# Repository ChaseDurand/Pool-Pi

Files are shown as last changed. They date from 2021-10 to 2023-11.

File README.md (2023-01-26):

# Logo icon Pool-Pi

Pool-Pi is a hardware+software system for interfacing with Goldline/Hayward Aqualogic pool control boards over WiFi via a Raspberry Pi. It adds wireless capabilities to non-wireless control boards and a web interface for viewing updates and sending commands.

<p align='center'>
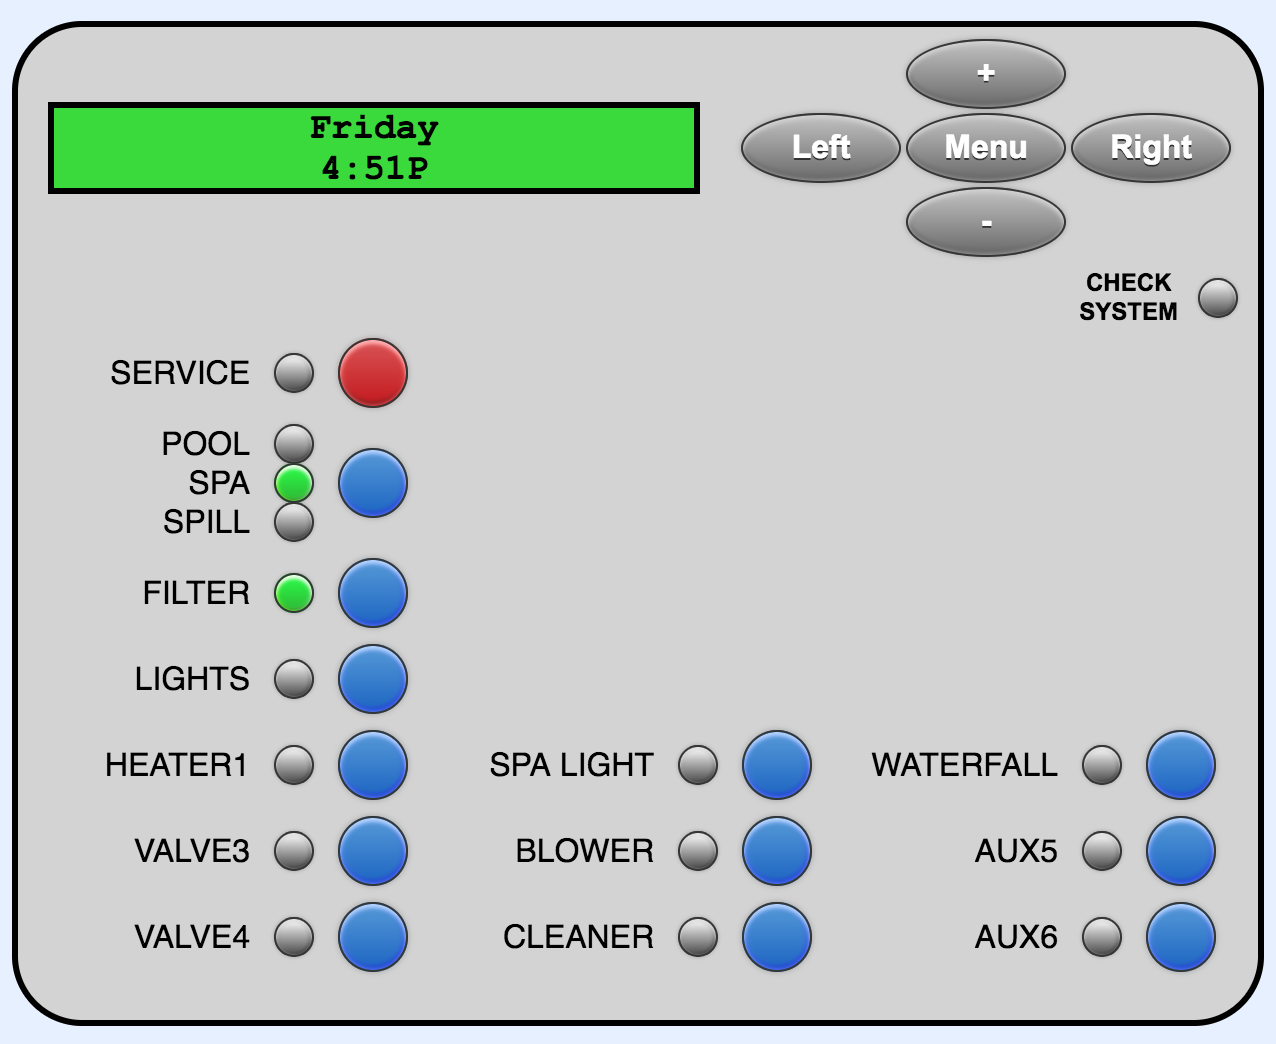
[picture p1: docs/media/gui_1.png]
    
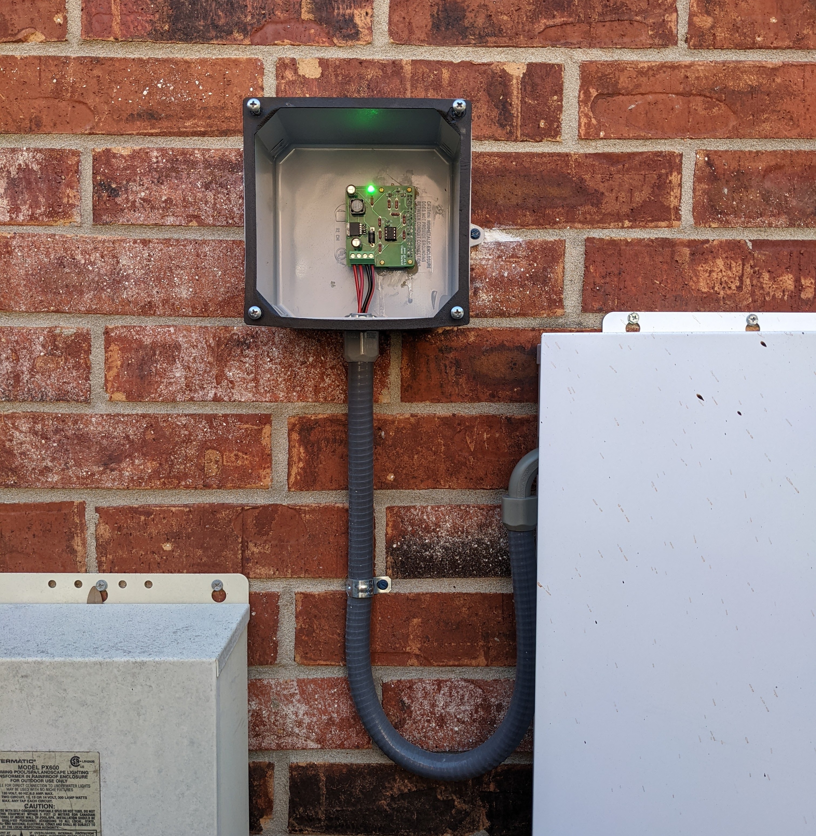
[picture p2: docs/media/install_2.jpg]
    
</p>

## Demo Video
This video shows multiple clients interfacing with the unit and demonstrates display updates, button presses, menu controls, blinking display characters, and LED updates.

https://user-images.githubusercontent.com/50851884/149863222-32523871-b4b8-4c59-9fa8-fe185a0315eb.mov

## Overview
<p align='center'>
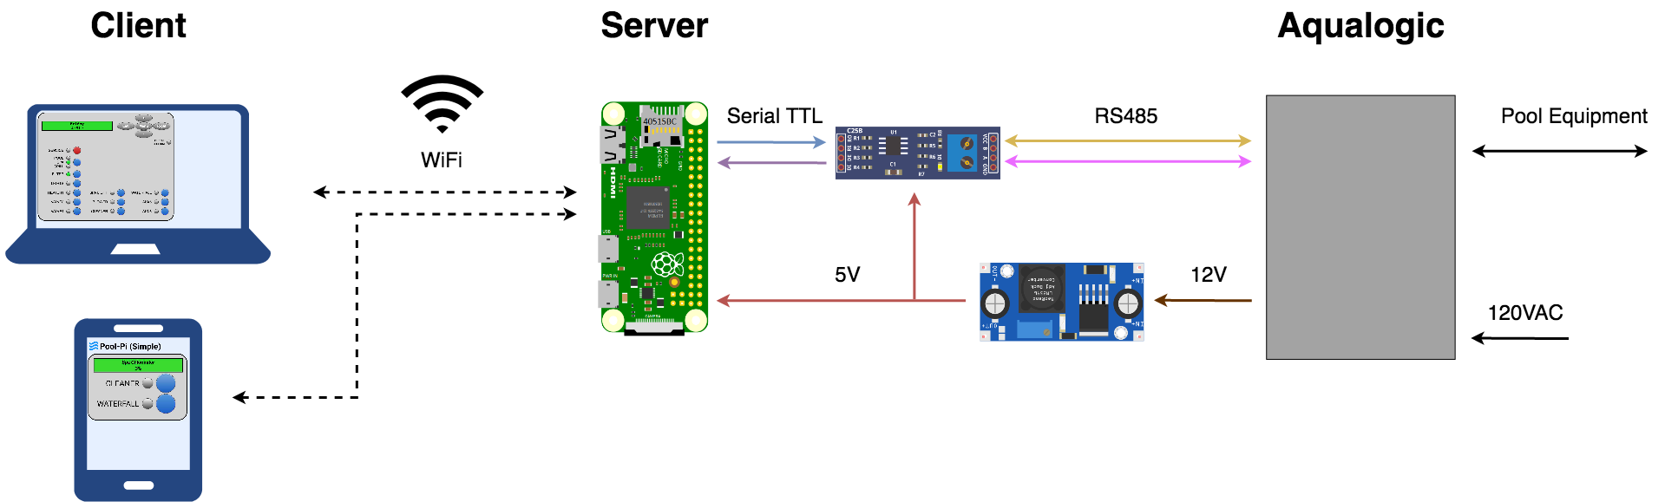
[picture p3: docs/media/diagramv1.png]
Diagram

</p>

Pool-Pi provides a web interface which emulates a local PS-8 display, allowing for the same controls accessible from the physical unit. The serial bus exposes all 14 aux relays regardless of local display, so emulation of a PS-16 display is possible, allowing additional relays to be added without purchasing a larger local interface. An RS485 adapter is used to read and send messages in accordance with the [Aqualogic serial communication protocol](/docs/PROTOCOL_NOTES.md), mimicking an OEM device. The system also adds logging, which is unavailable on the OEM unit. A simplified GUI is available to show the most frequently used commands.
<p align='center'>
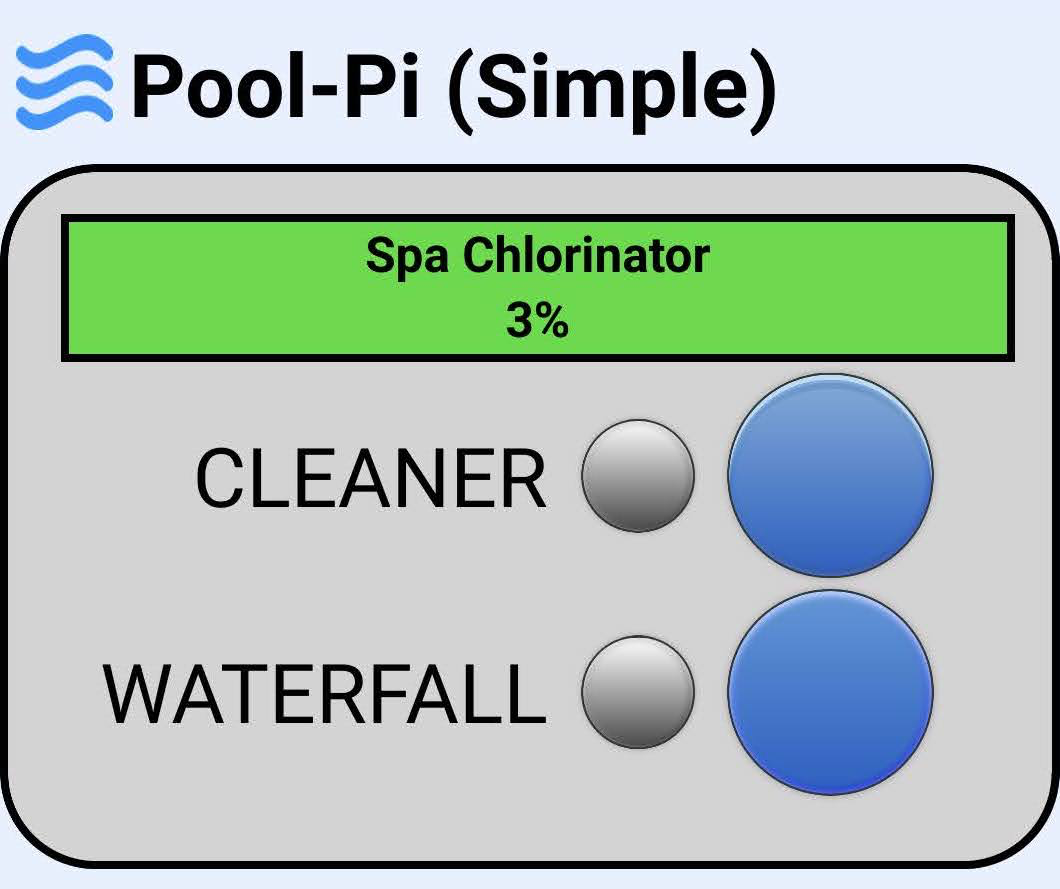
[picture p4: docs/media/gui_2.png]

</p>

## Setup
Project requirements and instructions can be found in [docs/SETUP.md](/docs/SETUP.md).

## Acknowledgements
Thank you to other people who have put their own resources/solutions for solving this problem online, including [draythomp](http://www.desert-home.com/), [swilson](https://github.com/swilson/aqualogic), and Pete Tompkins.

## Disclaimer
This project is not endorsed or affiliated with Goldline/Hayward in any way.

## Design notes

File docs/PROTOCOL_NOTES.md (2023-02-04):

# Aqualogic RS485 Protocol Notes

The RS485 protocol that the Aqualogic board uses is not fully documented. The most official information can be found in the manual for the AQ-CO-SERIAL, a device designed to interface between a Prologic/Aqualogic unit and a home automation system by converting RS485 messages to RS232. However, the AQ-CO-SERIAL strips some messages from the serial bus, slightly modifies some commands, and handles response timing to the master unit, so a substitute must handle all messages and timing.

The serial bus is used to communicate between the Aqualogic board, the local display, and any additional devices (wired controllers, spa controllers, wireless adapters such as the GLX-BASE-RF). All devices on the bus are connected in parallel.

The protocol use 1 start bit, 8 data bits, no parity, and 2 stop bits with a baud rate of 19.2k.

Frames are structured with DLE STX (x10x02), two bytes indicating the origin device and command, multiple data bytes, a two byte checksum, and DLE ETX (x10x03). The two byte checksum includes all bytes before the checksum (excluding DLE STX). If any byte besides the start and end DLE (x10) are equal to x10, a NULL (x00) is inserted immediately after that byte. This NULL must be removed when parsing frames.

| Start | Frame Type | Command/Data | Checksum | End |
| :---: | :---:| :---: | :---: | :---: |
| x10x02 | <2 bytes> | <0-? bytes> | <2 bytes> | x10x03 |

## Aqualogic to Controller
The Aqualogic board acts as a master unit providing a heartbeat/keep alive packet, screen updates, and LED updates.

A keep alive frame is sent every 100ms with a frame type of x01x01 and zero data bytes. If any serial device has a message to send, it must respond immediately after the keep alive frame. OEM controllers and display devices begin responding 0.5ms after the end of the keep alive frame. The Aqualogic sends any other commands 40ms after the end of the keep alive packet.

Keep alive frame: x10x02x01x01x00x14x10x03

Screen updates have the frame type x01x03. Different devices have different screen sizes (2 by 16 instead of 2 by 20). I do not know if different display packets are sent, or if the local displays parse frames differently to accomodate different screen sizes. There might be a handshake between the Aqualogic and any connected devices on startup to communicate screen size and software versions (which could also explain Communication Err 1). A NULL x00 is inserted after the display bytes.

Blinking characters are used to indicate selections on menus and time. To indicated blinking, the highest bit (1<<7) is set as 1 on a per character basis. For example, the colon symbol : almost always appears as blinking (xBA instead of x3A).

The degree symbol ° is encoded as an underscore (x5F) and must be replaced with xC2xB0.

In service mode, regular screen updates have the frame type of x02x03 and are immediately followed with display updates containing info about service mode with frame type of x03x03. The local display only displays the initial x02x03 update. The x03x03 service mode update is logged.

LED updates have the frame type x01x02. The first 4 bytes indicate on/off, and the second 4 bytes indicate blinking (if the corresponding on/off bit is also on). Within the bytes, a single bit corresponds to a specific LED.

| Start | Frame Type | LEDs1 | LEDs2 | LEDs3 | LEDs4 | Blink LEDs1 | Blink LEDs2 | Blink LEDs3 | Blink LEDs4 | Checksum | End |
| :---: | :---:| :---: | :---: | :---: | :---: | :---: | :---:| :---: | :---: | :---: | :---: |
| x10x02 | x01x02 | <1 byte> | <1 byte> | <1 byte> | <1 byte> | <1 byte> | <1 byte> | <1 byte> | <1 byte> | <2 bytes> | x10x03 |

The bit mask for each LED is shown below. The order of the LEDs is unintuitive because it reflects the evolution of the platform and its capabilities (AQL-P-4 to PS-8 to PS-16, each adding more parameters):

Example LED frame with Pool, Filter, and Aux4 On: x10x02x01x02x28x08x00x00x00x00x00x00x00x45x10x03

| Byte | Bit | Mask | LED |
| :---: | :---:| :---: | :--- |
| LEDs1 | 0 | 1<<0 | Heater1 |
| LEDs1 | 1 | 1<<1 | Valve3 |
| LEDs1 | 2 | 1<<2 | Check System |
| LEDs1 | 3 | 1<<3 | Pool |
| LEDs1 | 4 | 1<<4 | Spa |
| LEDs1 | 5 | 1<<5 | Filter |
| LEDs1 | 6 | 1<<6 | Lights |
| LEDs1 | 7 | 1<<7 | Aux1 |
| LEDs2 | 0 | 1<<0 | Aux2 |
| LEDs2 | 1 | 1<<1 | Service |
| LEDs2 | 2 | 1<<2 | Aux3 |
| LEDs2 | 3 | 1<<3 | Aux4 |
| LEDs2 | 4 | 1<<4 | Aux5 |
| LEDs2 | 5 | 1<<5 | Aux6 |
| LEDs2 | 6 | 1<<6 | Valve4/Heater2 |
| LEDs2 | 7 | 1<<7 | Spillover |
| LEDs3 | 0 | 1<<0 | System Off |
| LEDs3 | 1 | 1<<1 | Aux7 |
| LEDs3 | 2 | 1<<2 | Aux8 |
| LEDs3 | 3 | 1<<3 | Aux9 |
| LEDs3 | 4 | 1<<4 | Aux10 |
| LEDs3 | 5 | 1<<5 | Aux11 |
| LEDs3 | 6 | 1<<6 | Aux12 |
| LEDs3 | 7 | 1<<7 | Aux13 |
| LEDs4 | 0 | 1<<0 | Aux14 |
| LEDs4 | 1 | 1<<1 | Super Chlorinate |
| LEDs4 | 2 | 1<<2 | (unused) |
| LEDs4 | 3 | 1<<3 | (unused) |
| LEDs4 | 4 | 1<<4 | (unused) |
| LEDs4 | 5 | 1<<5 | (unused) |
| LEDs4 | 6 | 1<<6 | (unused) |
| LEDs4 | 7 | 1<<7 | (unused) |

## Controller to Aqualogic
Even though the PS-4/8/16 remotes know the state of the pool system through LED messages, all commands from this series act as toggle switches and are independent of the current state; There are no separate on/off commands for this series of remotes. The frame type from a local PS-8 is x00x02.

Example Aux 1 button toggle frame: x10x02x00x02x00x02x00x00x00x02x00x00x00x1Cx10x03. If Aux 1 is off, this will turn it on. If Aux 1 is on, this will turn it off.

| Function | Command |
| :--- | :--- |
| Service | x08x00x00x00 |
| Pool/Spa/Spillover | x40x00x00x00 |
| Filter | x00x80x00x00 |
| Lights | x00x01x00x00 |
| Heater1 | x00x00x04x00 |
| Valve3 | x00x00x01x00 |
| Aux1 | x00x02x00x00 |
| Aux2 | x00x04x00x00 |
| Aux3 | x00x08x00x00 |
| Aux4 | x00x10x00x00<sup>[1](#footnote1)</sup> |
| Aux5 | x00x20x00x00 |
| Aux6 | x00x40x00x00 |
| Aux7 | x00x80x00x00 |
| Aux8 | x00x00x08x00 |
| Aux9 | x00x00x10x00<sup>[1](#footnote1)</sup> |
| Aux10 | x00x00x20x00 |
| Aux11 | x00x00x40x00 |
| Aux12 | x00x00x80x00 |
| Aux13 | x00x00x00x01 |
| Aux14 | x00x00x00x02 |

## Variable Speed Pump Control
Aqualogic supports Hayward variable speed pumps that send their own frame type with speed and power information. I don't have a Hawyard VSP, so I am not able to implement support.

## Configuration Menu
The configuration menu is used for the Aqualogic's initial setup and when connecting new pool equipment. The configuration menu is unlocked by holding the left and right menu buttons for a few seconds. Because this sub-menu is seldom used and would only be used when the user is physically present with the Aqualogic, I did not implemenet it.

## Exposing Additional Aux Relays
The PS-4/8/16 boards use the same PCB, so each board can support up to 14 aux relays regardless of local interface. Because Pool-Pi can expose all of the available aux controls, additional relays could be added and controlled without purchasing a larger PS-8/16 local display.

## Legacy On/Off Commands
While commands from the PS-4/8/16 series are the same for on/off, older controllers such as the AQL-SS-RF and AQL-P-4 use slightly modified commands with separate on/off capabilities. The frame type is x00x05. The commands are repeated twice and end with x7F before the checksum. While using these commands would make programming far easier, these on/off commands only cover a subset of the PS-4/8/16 controls. Because my setup involves commands outside of this subset and I achieved high reliability with only the toggle commands, I did not implement them.

Example Aux 2 On frame: x10x02x00x05x08x00x08x00x7Fx00xA6x10x03. If Aux 2 is off, this will turn it on. If Aux 2 is already on, this has no effect.

| Function | Command |
| :--- | :--- |
| Heater On  | x01x00 |
| Heater Off | x00x01 |
| Filter On  | x02x00 |
| Filter Off | x00x02 |
| Pool On | x04x00 |
| Spa On | x00x04 |
| Aux 2 On | x08x00 |
| Aux 2 Off  | x00x08 |
| Aux 1 On | x10x00<sup>[1](#footnote1)</sup> |
| Aux 1 Off  | x00x10<sup>[1](#footnote1)</sup> |
| Light On | x20x00 |
| Light Off  | x00x20 |

<a name="footnote1">1</a>: An extra x00 must be inserted after x10, not shown here

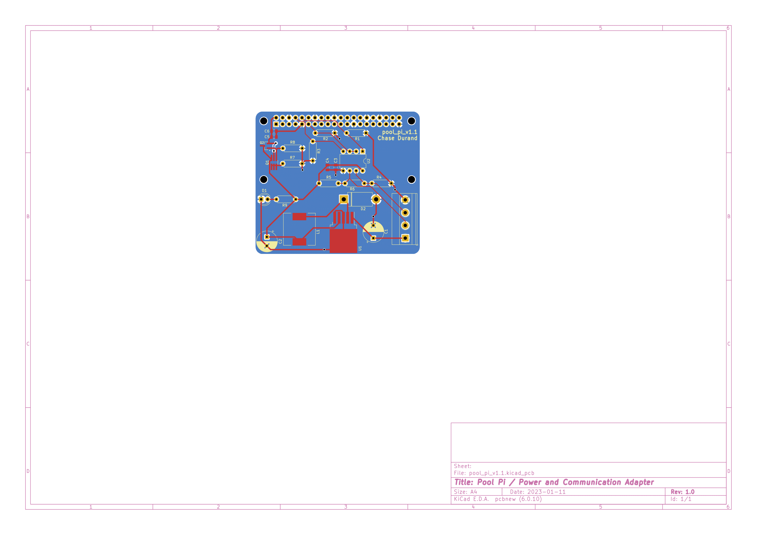
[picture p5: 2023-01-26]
docs/media/pool_pi_v1.1_layout.png

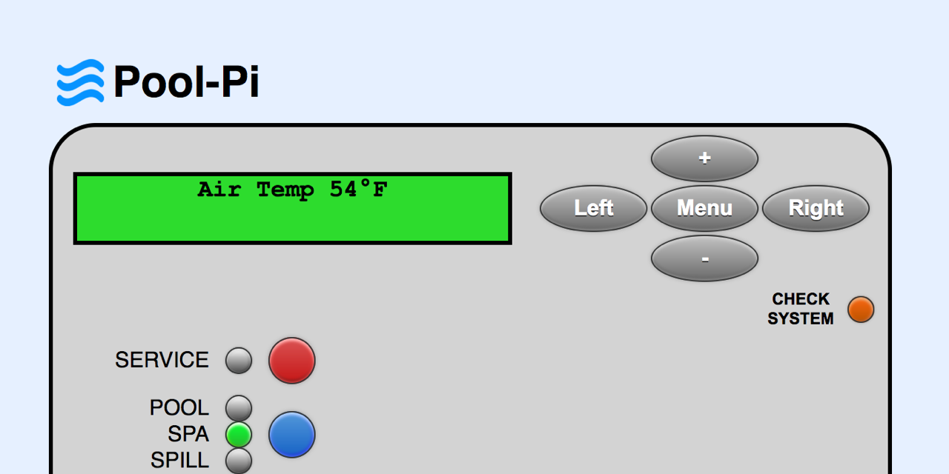
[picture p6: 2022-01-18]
docs/media/poolpi_url_preview.png

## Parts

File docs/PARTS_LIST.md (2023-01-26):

# Parts List

This list reflects the parts that I used for my specific installation, not exact part requirements. The total cost using off the shelf components was ~$60.

| Name | Manufacturer | Model | Quantity |
| :--- | :---| :--- | ---: |
| Raspberry Pi | Raspberry Pi Foundation | Zero W | 1 |
| Micro SD Card | Samsung | MB-MC32GA | 1 |
| Junction Box (6"x6"x4") | Cantex | R5133710 | 1 |
| 1/2" Conduit (6' Kit) | Southwire | 58004507 | 1 |
| 1/2" 1-Hole Strap | Halex | 26151 | 1 |
| 1/4" Concrete Screws | Tapcon | 24330 | 3 |
| Stranded Wire | Consolidated | 16 AWG Stranded | 36' |
| Buck Boost Converter | DZS Elec | LM2596 DC-DC HW-411 | 1 |
| TTL to RS485 Adapter | LC Electronics | 2046l | 1 |
| 1K Resistor | NA | NA | 1 |

The BOM for the PCB is shown below. This replaces the off the shelf power and communication adapter boards.

| Name | Manufacturer | Model | Quantity |
| :--- | :---| :--- | ---: |
| 100uF Low ESR Electrolytic Capacitor | Panasonic | EEU-FR1H101B | 1 |
| 180uF Low ESR Electrolytic Capacitor | Panasonic | EEU-FR1V181 | 1 |
| 10uF Ceramic Bypass Capacitor | KEMET | C0805C106K8PAC | 2 |
| 0.1uF Ceramic Bypass Capacitor | KEMET | C0805C104M5RACTU | 2 |
| Green LED | Cree | C4SMA-GGY-CU2W37A1 | 1 |
| Schottky Diode | Vishay | 1N5820-E3/73 | 1 |
| 2x20 Header | TE Connectivity | 7-534206-0 | 1 |
| 4 Post Terminal Blockr | Phoenix Contact | 1711042 | 1 |
| 68uH Inductor | Coilcraft | MSS1278H-683KED | 1 |
| BJT Matched PNP | Diodes Incorporated | DMMT5401-7-F  | 1 |
| MOSFET P-Ch | Diodes Incorporated | DMG2305UX-13 | 1 |
| 120 Resistor | Vishay | CCF07120RGKE36 | 1 |
| 200 Resistor | Vishay | CCF07200RGKE36 | 1 |
| 10K Resistor | Vishay | CCF0710K0JKE36  | 4 |
| 20K Resistor | Vishay | CCF0720K0JKE36 | 2 |
| 47K Resistor | Vishay | CCF0747K0JKE36 | 1 |
| 5V Voltage Regulator | Texas Instruments | LM2596S-5.0/NOPB  | 1 |
| RS-485 Interface | Maxim | MAX485EPA+ | 1 |

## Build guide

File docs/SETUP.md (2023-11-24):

# Setup

## Project Requirements
* Goldline/Hayward Aqualogic control board (tested on Main Software Revision 2.86)
* Raspberry Pi with Wifi
* Adjustable DC-DC step down buck boost converter (or equivalent hardware)
* TTL to RS485 adapter (or equivalent hardware)
* Installation hardware:
    * Weatherproof junction box
    * Non metalic liquid tight flexible conduit
    * Concrete screws
    * Wire
    * 
* Tools:
    * Multimeter
    * Drill
    * Screwdriver

Exact parts used can be found in the [parts list](./PARTS_LIST.md).

## Software Setup
* Setup a Raspberry Pi headless with WiFi, a static IP, and SSH access [(example tutorial from Avram Piltch on Tom's Hardware)](https://www.tomshardware.com/reviews/raspberry-pi-headless-setup-how-to,6028.html).
* From a device on the same network, connect to the Pi via SSH.

        ssh pi@192.168.###.###
* Install git.

        sudo apt update
        sudo apt install git

* Install pip.

        sudo apt install python3-pip

* Install redis.

        sudo apt install redis

* Enable UART.

        sudo raspi-config
        
    From the interface, navigate to 5 Interfacting Options, P6 Serial. No login shell, Yes serial port enabled.

        sudo reboot

* Clone this repository into the home directory.

        git clone --depth 1 https://github.com/ChaseDurand/Pool-Pi.git
* Set the Pi's timezone for accurate time stamps in log file.
   * View timezone options.

           timedatectl list-timezones     
   * Set timezone.

           sudo timedatectl set-timezone YOUR_TIME_ZONE
* Run setup.sh to install python modules and configure systemd to run pool-pi.py on startup.

        sudo /home/pi/Pool-Pi/setup/setup.sh
* Confirm the status of the service.

        systemctl status poolpi.service
* Confirm log file creation.

        tail /home/pi/Pool-Pi/logs/pool-pi.log
* Complete the hardware setup steps outlined below.
* From a device on the same network, navigate to your Pi's IP address on port 5000 (ex. 192.168.###.###:5000) to access the GUI. To access the simplified GUI, add /simple.

## Hardware Setup
The system taps into the Aqualogic's power and serial busses via the 'REMOTE DISPLAY' connections on the top left of the board.
* RED 1 = ~11V
* BLK 2 = RS485 DATA A (-)
* YEL 3 = RS485 DATA B (+)
* GRN 4 = Ground 0V

<p align='center'>
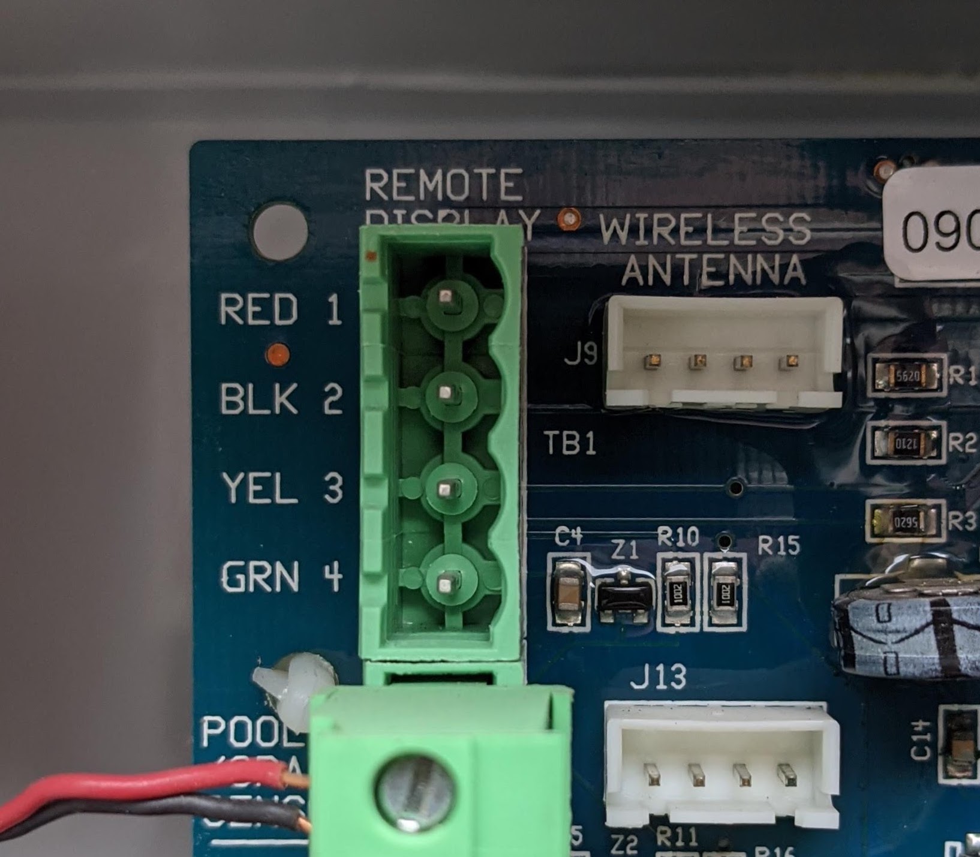
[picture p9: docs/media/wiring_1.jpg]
Pins on Aqualogic board
  
</p>

If these are occupied, the J9 WIRELESS ANTENNA or J13 headers can be used, but the pins are laid out in a different order.

My initial prototypes used an off the shelf buck-boost converter and TTL to RS485 adapter, but I have replace them with a custom PCB that serves the same purposes.

If an adjustable DC-DC converter is used, the output needs to be set to 5V. On my RS485 adapter, read enable (RE) is innacurately labeled and is actually ~RE. If your RS485 adapter board includes pull ups on DE, they must be overriden with a pull down to prevent the board from trying to transmit while the Pi is booting, otherwise the Pi GPIO will be pulled to 5V and the Aqualogic won't boot correctly. The Raspberry Pi Zero W doesn't include a fuse on the micro USB PWR IN, which is directly tied to all 5V pins. If a different Raspberry Pi model that contains a fused power input is used, then power should be supplied through the USB port instead of a 5V pin.

<p align='center'>
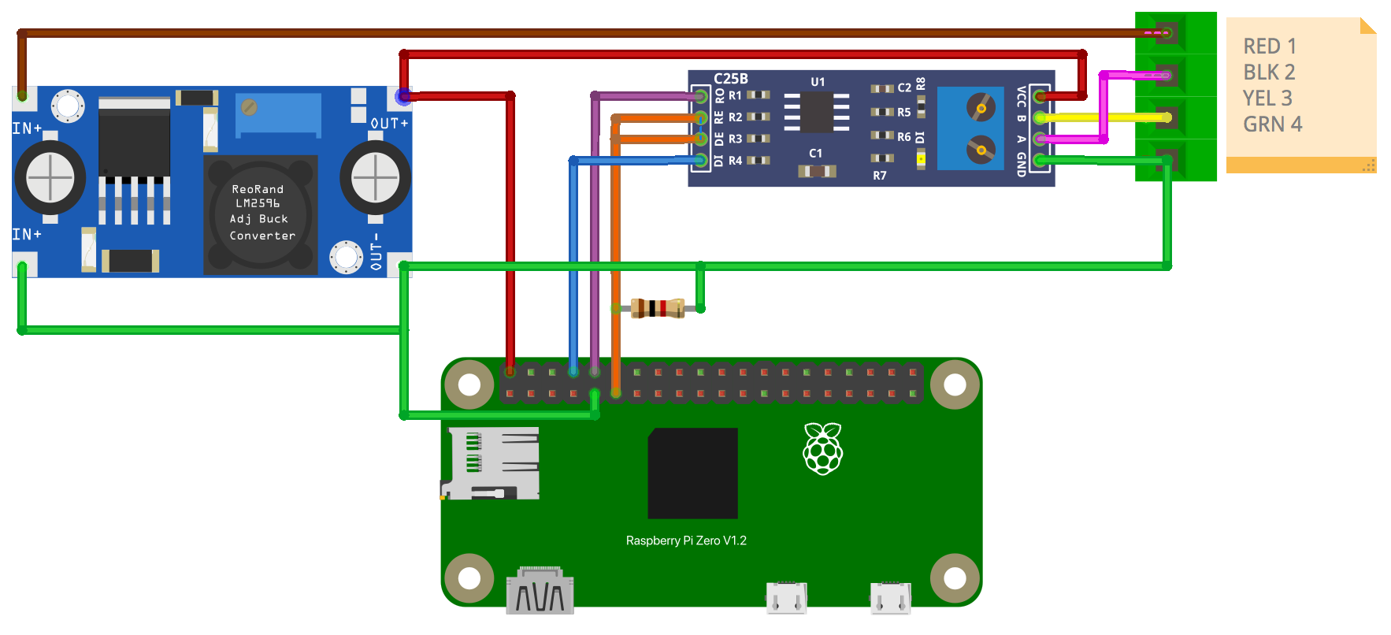
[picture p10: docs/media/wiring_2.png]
Wiring diagram with off the shelf parts
   
</p>

While I had no issue with the off the shelf parts for over a year, I replaced them with a custom PCB. KiCad 6 board and schematic files can be found in [/docs/pcb](/docs/pcb).

<p align='center'>
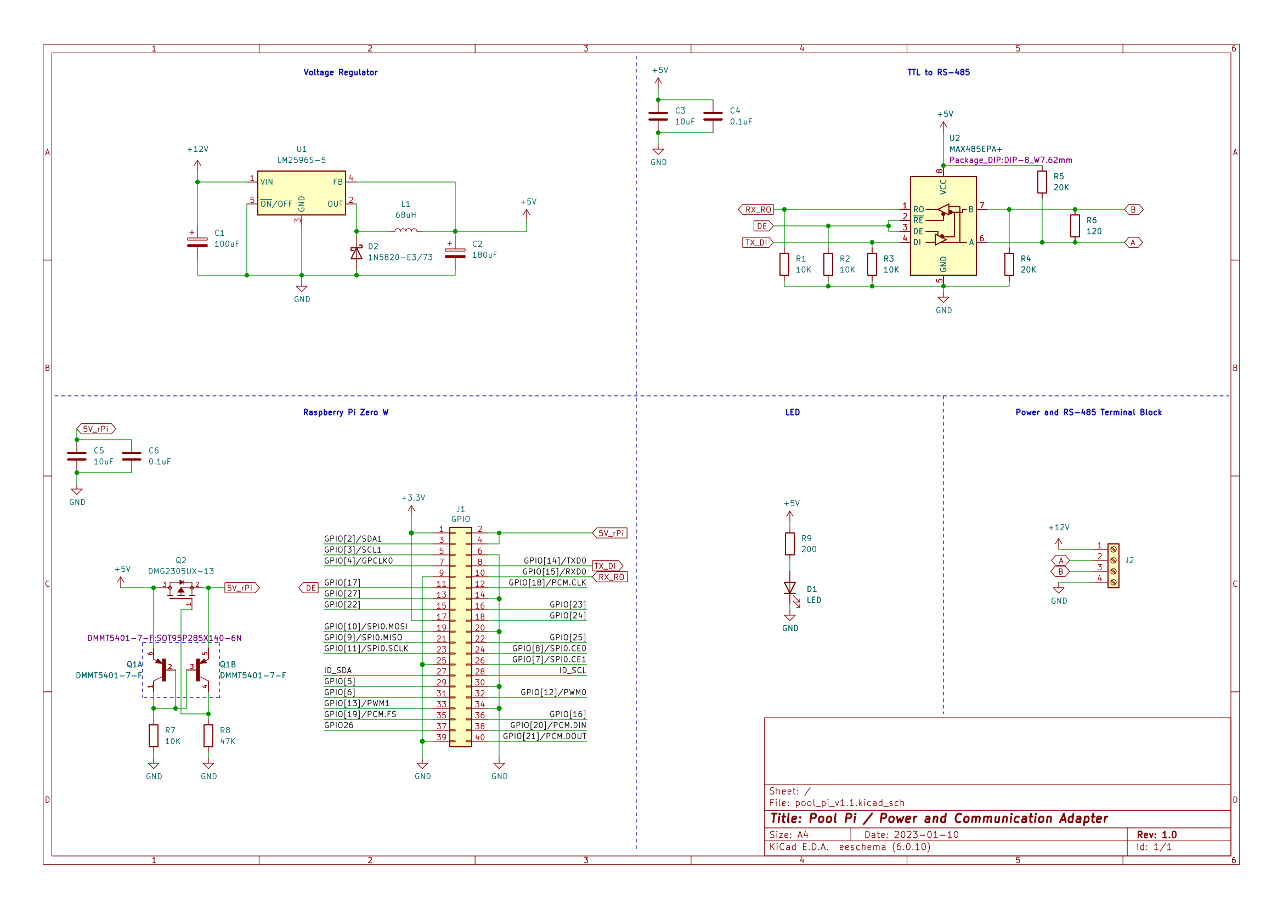
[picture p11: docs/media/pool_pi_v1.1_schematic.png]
Wiring diagram
   
</p>

Mount enclosure to exterior wall using concrete screws or appropriate fasterners. I drilled an improperly sized hole and used weatherproof sealant to fix it. Route x4 wires (x2 low voltage wires and x2 RS485) through weatherproof conduit into Aqualogic enclosure. After confirming functionality, I used construction adhesive to attach M3 metal standoffs to the inside of the enclosure.

<p align='center'>
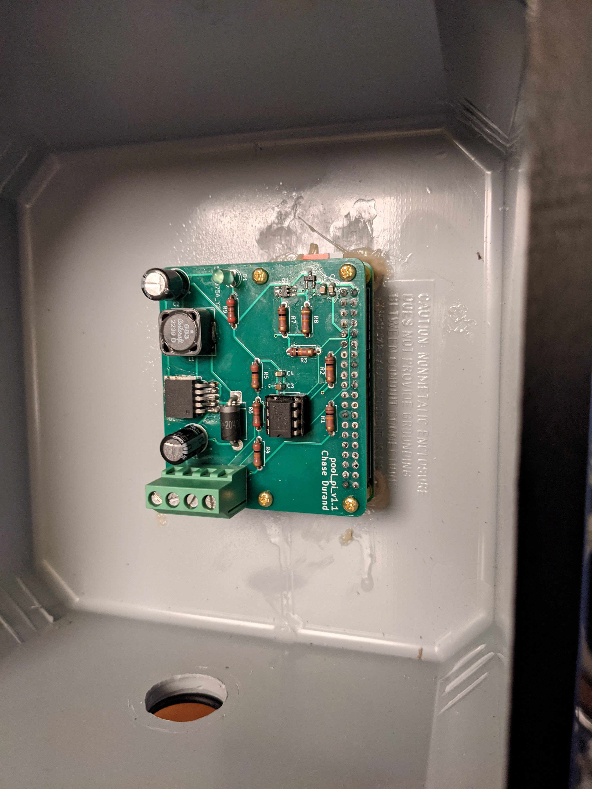
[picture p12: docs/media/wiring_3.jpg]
Components mounted in weather proof enclosure
    
</p>

<p align='center'>
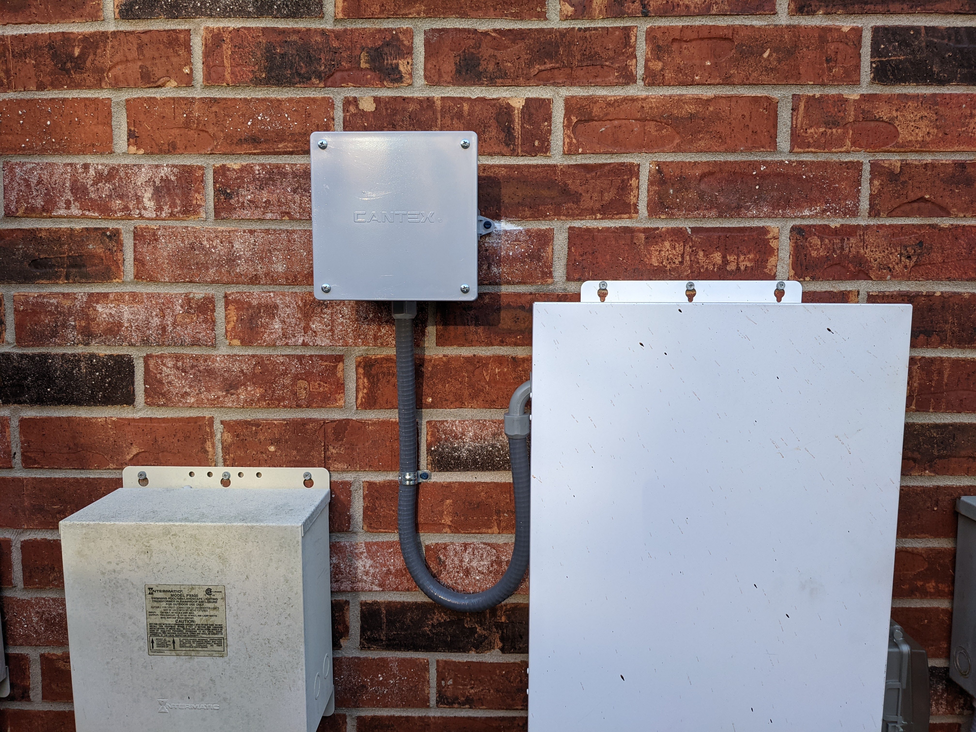
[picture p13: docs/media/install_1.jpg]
Example installation of system
   
</p>

## Troubleshooting
Communication Error can appear when multiple devices attempt to drive the serial bus simultaneously.
* Communication Err 1 (CE1) is a startup error that occurs when the local display is unable to communicate with the main control board when it powers up. This could be due to the RS485 adapter being in transmit mode on startup, as seen with CE2. Unlike CE2, this error does not clear automatically when the serial lines are cleared. To clear the error, the local display must be disconnected and reconnected. If CE1 persists after this, the main board must be power cycled via the breaker that feeds it.
* Communication Err 2 (CE2) occurs when multiple devices attempt to write to the serial bus simultaneously. Depending on the hardware configuration, this error might occur when the Pool-Pi is powered off due to the RS485's state when powered off. To fix this, ensure that the RS485 adapter is set to receive when not transmitting.

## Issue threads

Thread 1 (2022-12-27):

Question about setup

rpaldrich, 2022-12-27:
Good morning! This setup looks awesome. I have had Swilson's HA running for a few years now, but always wanted to be able to control more things (like service mode, pool/spa selection, etc).

I'm having some trouble with the services though (myservice specifically) and do not know / understand what I am doing incorrectly. The log file is also not being generated.

This is what spits out after running the setup.ph file prior to rebooting.
```
Failed to enable unit: Unit file myscript.service does not exist.
Setup complete.
Rebooting in 10 seconds.
```
And when I continue following the directions, this is the output;
"Confirm the status of the service":
```
pi@raspberrypi:~/Pool-Pi/src $   systemctl status poolpi.service
 poolpi.service - Pool-Pi Service
   Loaded: loaded (/lib/systemd/system/poolpi.service; disabled; vendor preset:
   Active: inactive (dead)
```

rpaldrich, 2022-12-28:
Thanks a lot! --- I'm waiting for the RS485 converter to arrive, but I was able to start pool-pi by executing the pool-pi.py file and successfully connected to the IP:5000 server.  The pool-pi "service" does not seem to be starting though, or if it is, does not get triggered. What triggers the the service to start? I'm not super familiar with the linux environment; do services allow the RPI to do other things while running pool-pi in the background?

rpaldrich, 2023-01-05:
Merry Christmas and HNY. This project was an exercise in programming for sure, but super rewarding when I got most of it to work. I'm still struggling with the pool/spa/spillover. I'm going to post my write up step by step just so that if someone else comes by with a brand new RPI and not much knowledge they can get this to work. My controller is slightly different than yours, but the overall backend seems extremely similar. Unsure if the issues I ran into are specific to the controller differences or what not.

RPI model: Zero W 1.1
RPI software: Raspbian (Bullseye)
Pool Controller: AquaPlus (See pic below)
Aquaplus Main S/W Revision 4.40
Aquaplus display Revision 3.12
Pump: Two-Speed Pump

Outstanding stuff remaining:
- #1 priority and help requested: Figure out why the pool/spa/spillover function fails (I'm going to write a separate issue).
- Integrate the config file stuff to automatically update the web template
-Figure out, config file notwithstanding, why updating web template causes program to get stuck in an endless update loop where the program is unresponsive.
- Update the seemingly different commands to change from Low-Speed filter to Off, and from 3 hour service mode to service mode off (details below)

**Here is my write-up, think of this as "I've got a brand new RPI"**

1. Burn an image onto SD card-- I used RPI imager and burned RPI OS LITE
2. Ensure you go to settings prior to burning the image, turn on SSH, change password of RPI, note the hostname or change it, and input your WIFI SSID + PW.
3. Download on your computer a SSH app. I use puTTY
4. Turn on RPI and give it a couple of minutes to connect
5. Figure out the IP address of your RPI. I used windows CMD prompt and typed arp -a and used process of elimination. Other methods exist
6. Use that IP address and SSH in. Click yes on the pop up box for the first time you ssh in. Input user name and password
7. Once in, type and/or follow the below commands in your RPI:
8. _These commands will update some stuff and get you ready to run_
9. sudo apt-update
10. sudo apt-upgrade
11. sudo apt install python3-pip
12. _Now you'll want to update the static IP settings so it doesn't change IP settings on you during next boot._
	sudo nano /etc/dhcpcd.conf
		interface wlan0
		static ip_address=192.168.xx.xx
		static routers=192.168.86.1
		static domain_name_servers=192.168.86.1
13. W_e will need to make "something" called an SSH key on our RPI, and then copy the public key back to your laptop to upload onto github. I use vsftpd on my laptop. I think there are more secure options, but anyway here you go;_
14. https://linuxize.com/post/how-to-setup-ftp-server-with-vsftpd-on-raspberry-pi/
	sudo apt-install vsftpd
	sudo systemctl status vsftpd
	sudo nano /etc/vsftpd.conf
	mkdir /home/pi/ftp
	chmod 700 /home/pi/ftp
15. _As of Dec 2022 RPI comes enabled with the serial console ON, which messes up your serial commands you'll want, so we need to turn it off;_
	sudo raspi-config
	go to interfacing
		go to serial
			select serial console no
			select serial hardware yes
16. _Now generate the SSH key to allow you to connect to github;_
	cd ~/.ssh || mkdir -p $HOME/.ssh && chmod 0700 $HOME/.ssh && ssh-keygen && mv id_rsa.pub /home/pi/ftp
	Now use vsftpd along with static IP address and name/pw to log in, and transfer the PUBLIC (.pub) key to computer, open in notepad, copy it to the clipboard, then make a github account, go to settings, go to SSH key section, name it whatever you want and then paste the key into the box.
17. _Now lets get the pool-pi program_
https://github.com/ChaseDurand/Pool-Pi/blob/master/docs/SETUP.md
	sudo apt install git
	sudo /home/pi/Pool-Pi/setup/setup.sh
	pip3 install pyserial
	systemctl status poolpi.service
	cd Pool-Pi/src
	nano model.py
		change ttyamao to serial0     **this seems like a change from original code, because RPI updated name of port**
		ctrl+x then enter
	python3 pool-pi.py
	If you reboot, pool.service will start, but for some reason does not allow the program to run. So you must manually end pool.service, by using the below command, than manually start it up.
		systemctl stop poolpi
		https://linuxhint.com/stop-services-raspberry-pi/
       Navigate on a computer browser to IPaddress:5000

18. At this point you might be fully functional, especially if you have the same controller that Chase does. But for me, I was receiving just fine from the controller. Any button pressed outside on my pool panel was reflected on my webserver. When I clicked a button on the server though, it would wind up in an endless updating .gif and not do anything, requiring a restart. The menu buttons didn't do anything either. So I had to edit the command.py file;
19. Force quit the pool-pi program by pressing CTRL+C
20. _back in the ~/src folder;_
21. nano commands.py
22. _Update the following_
   ```
  button_toggle = {
    'service': b'\x08\x00',
    'pool': b'\x40\x00',
    'spa': b'\x40\x00',
    'spillover': b'\x40\x00',
    'filter': b'\x80\x00',
    'lights': b'\x00\x01',
    'heater1': b'\x00\x00\x04\x00',
    'valve3': b'\x00\x00\x01\x00',
    'valve4': b'\x00\x00\x02\x00',
    'aux1': b'\x00\x02',
    'aux2': b'\x80\x00',
	# actual aux2 line is as follows, but was changed to allow to use this button to turn down pump from lo speed
	#'aux2':b'\x00\x04',
    'aux3': b'\x00\x08\x00\x00',
    'aux4': b'\x00\x10\x00\x00',
    'aux5': b'\x00\x20\x00\x00',
    'aux6': b'\x00\x40\x00\x00',
    'aux7': b'\x00\x80\x00\x00',
    'aux8': b'\x00\x00\x08\x00',
    'aux9': b'\x00\x00\x10\x00',
    'aux10': b'\x00\x00\x20\x00',
    'aux11': b'\x00\x00\x40\x00',
    'aux12': b'\x00\x00\x80\x00',
    'aux13': b'\x00\x00\x00\x01',
    'aux14': b'\x00\x00\x00\x02'
}

buttons_menu = {
    'left': b'\x04\x00',
    'right': b'\x01\x00',
    'plus': b'\x20\x00',
    'minus': b'\x10\x00',
    'menu': b'\x02\x00'
}

```
_Note on updated commands:_
I used a serial converter to read the raw serial data as I pushed my controller buttons. The codes that were sent by the hayward control panel are reflected above in my updated code, as well in the serial.xlsx file below.

_Everything works, except for pool/spa/spillover_

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
[Serial Data.xlsx](https://github.com/ChaseDurand/Pool-Pi/files/10352239/Serial.Data.xlsx)

rpaldrich, 2023-01-07:
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

poolpi.service is working now; I was receiving an error when the systemd tried to start it;

> RuntimeError: The Werkzeug web server is not designed to run in production. Pass allow_unsafe_werkzeug=True to the run() method to disable this error."

But it would work fine if I just started it manually. Turns out Werkzeug or Socket was updated late 2022 and it started throwing this error.  Simple fix -- run the below code;
`pip3 install flask-socketio==5.2.0`

Closed 2023-01-07.

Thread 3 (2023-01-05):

Pool/Spa/Spillover

rpaldrich, 2023-01-05:
I am having one issue. The pool/spa/spillover button passes me the following error;
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

Any idea what my problem is? I didn't change any of the code except for the command.py file for specific commands serial data going to the controller?

I'm curious if this is caused by another issue I'm having. It seems pool-pi does not pass my controller correct serial commands to cycle from Filter On (high speed) to Filter On (low speed) to Filter Off. Perhaps this is part of the issue?

rpaldrich, 2023-01-11:
Chase -- I gave it a shot, but ran out of time. Will check it out again this weekend.

rpaldrich, 2023-02-10:
Chase -- been working on this for awhile now in my free time. I think I found where my error is coming from and I bet you know the solution basically immediately.

Front end (poolpi.js) _sends buttonVersion as null_ anytime pool-spa-spillover button is pushed. This seems to be because in line 138ish, `buttonVersion=this.getAttribute('version')` is referencing the pool-spa-spillover container, which is not "flex" and does not have a version associated with it. The individual pool/spa/spillover containers DO have versions associated with them, and they are flex, but the source for the version is never updated, and so the backend cannot parse it. How do I update the version? Or can the version be tied to the pool-spa-spillover container?

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

ChaseDurand, 2023-02-17:
Bad news: your observations are correct and I have no explanation. I could have sworn the pool/spa/spill buttons worked correctly but I just pulled an old version and they don't.

Good news: I coincidentally did some refactoring recently that fixed this issue. The system now only uses a single version for the entire state of the system instead of per parameter. However, I also moved the next state logic from the front end to the back end, which makes my comments about changing the filter and pool/spa from a month ago invalid. I believe my recent changes will currently work with your pool/spa only setup, just not the 2-speed motor.

Would you mind sharing your code with your changes? I think I'll be able to modify the logic in the back end for you. Also, feel free to reach out via my username at gmail if that communication medium works better for back and forth troubleshooting.

rpaldrich, 2023-02-17:
Ok so what I did to make the pool/spa thing work was this;
`        if (buttonID == 'pool-spa-spillover') {
            // Need to check which pool/spa/spillover is lit
            // Pool->Spa->Spillover
            if (!(document.getElementById('pool-spa-spillover').parentElement.parentElement.children['pool'].children['led'].classList.contains('off'))) {
                // Pool is on, need spa on
                buttonID = 'spa'
                buttonVersion='1'
                targetState = 'ON';
            }
`
and I added the "buttonVersion='1'" hard code to the spa, and if I ever use spillover I would do same.

The 2 speed pump motor is a weird one. I took your previous suggestions and incorporated, but it causes some cycling of the pump.  Let me mess around with it for a bit. github works great -- it is linked to email anyway.  I'm going to check out your new code and see how it works. Everything else in my version(s) is pretty much the same as yours, with exception of;

I slightly changed the commands because my controller serial command message is very slightly different.
I added buttonVersion to the poolpi.js file as above
I updated the model.py script to take into account the newer raspibian setup of my rpi zero.
`        self.ser = serial.Serial(port='/dev/serial0',
                                 baudrate=19200,
                                 parity=serial.PARITY_NONE,
                                 stopbits=serial.STOPBITS_TWO)
`
Other than that, everything else the same. Would need to check my walk-through for sure.

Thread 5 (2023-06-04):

can't obtain socket from wsgi enviroment

cwalker1960, 2023-06-04:
After a long struggle it seems to be running but when I open the web page i get "awaiting connection from rpi"
I see runtime error in the files cannot obtain socket. I know very little about programming was just hoping i could get this to work
Thanks in advance for any help you might offer me.

login as: pi
pi@pi's password:
Linux pi 6.1.21+ #1642 Mon Apr  3 17:19:14 BST 2023 armv6l

The programs included with the Debian GNU/Linux system are free software;
the exact distribution terms for each program are described in the
individual files in /usr/share/doc/*/copyright.

Debian GNU/Linux comes with ABSOLUTELY NO WARRANTY, to the extent
permitted by applicable law.
Last login: Sun Jun  4 07:59:23 2023 from 2603:6080:dbf0:8c40:8f6:ec76:d7a4:ef55
pi@pi:~ $ systemctl status poolpi.service
● poolpi.service - Pool-Pi Service
     Loaded: loaded (/etc/systemd/system/poolpi.service; enabled; vendor preset>
     Active: active (running) since Sun 2023-06-04 00:05:41 EDT; 10h ago
   Main PID: 409 (python3)
      Tasks: 2 (limit: 414)
        CPU: 30.894s
     CGroup: /system.slice/poolpi.service
             └─409 /usr/bin/python3 /home/pi/Pool-Pi/src/pool-pi.py

Jun 04 00:06:21 pi python3[409]:     self._target(*self._args, **self._kwargs)
Jun 04 00:06:21 pi python3[409]:  * Environment: production
Jun 04 00:06:21 pi python3[409]:    WARNING: This is a development server. Do n>
Jun 04 00:06:21 pi python3[409]:    Use a production WSGI server instead.
Jun 04 00:06:21 pi python3[409]:  * Debug mode: off
Jun 04 00:06:21 pi python3[409]:   File "/home/pi/Pool-Pi/src/pool-pi.py", line>
Jun 04 00:06:21 pi python3[409]:     serialHandler = SerialHandler()
Jun 04 00:06:21 pi python3[409]:   File "/home/pi/Pool-Pi/src/model.py", line 1>
Jun 04 00:06:21 pi python3[409]:     self.ser = serial0.Serial0(
Jun 04 00:06:21 pi python3[409]: NameError: name 'serial0' is not defined
lines 1-19/19 (END)
● poolpi.service - Pool-Pi Service
     Loaded: loaded (/etc/systemd/system/poolpi.service; enabled; vendor preset: enabled)
     Active: active (running) since Sun 2023-06-04 00:05:41 EDT; 10h ago
   Main PID: 409 (python3)
      Tasks: 2 (limit: 414)
        CPU: 30.894s
     CGroup: /system.slice/poolpi.service
             └─409 /usr/bin/python3 /home/pi/Pool-Pi/src/pool-pi.py

Jun 04 00:06:21 pi python3[409]:     self._target(*self._args, **self._kwargs)
Jun 04 00:06:21 pi python3[409]:  * Environment: production
Jun 04 00:06:21 pi python3[409]:    WARNING: This is a development server. Do not use it in a production dep>
Jun 04 00:06:21 pi python3[409]:    Use a production WSGI server instead.
Jun 04 00:06:21 pi python3[409]:  * Debug mode: off
Jun 04 00:06:21 pi python3[409]:   File "/home/pi/Pool-Pi/src/pool-pi.py", line 279, in main
Jun 04 00:06:21 pi python3[409]:     serialHandler = SerialHandler()
Jun 04 00:06:21 pi python3[409]:   File "/home/pi/Pool-Pi/src/model.py", line 104, in __init__
Jun 04 00:06:21 pi python3[409]:     self.ser = serial0.Serial0(
Jun 04 00:06:21 pi python3[409]: NameError: name 'serial0' is not defined
~
~
~
~
pi@pi:~ $ tail /home/pi/Pool-Pi/logs/pool-pi.log
2023-06-04 00:12:01 INFO     192.168.1.112 - - [04/Jun/2023 00:12:01] "POST /socket.io/?EIO=4&transport=polli ng&t=OY4cj4V&sid=rTkwyevVy-z9BylTAAAM HTTP/1.1" 200 -
2023-06-04 00:12:26 INFO     192.168.1.112 - - [04/Jun/2023 00:12:26] "GET /socket.io/?EIO=4&transport=pollin g&t=OY4cj4W&sid=rTkwyevVy-z9BylTAAAM HTTP/1.1" 200 -
2023-06-04 00:12:26 INFO     192.168.1.112 - - [04/Jun/2023 00:12:26] "POST /socket.io/?EIO=4&transport=polli ng&t=OY4cpCU&sid=rTkwyevVy-z9BylTAAAM HTTP/1.1" 200 -
2023-06-04 00:12:52 INFO     192.168.1.112 - - [04/Jun/2023 00:12:52] "GET /socket.io/?EIO=4&transport=pollin g&t=OY4cpCV&sid=rTkwyevVy-z9BylTAAAM HTTP/1.1" 200 -
2023-06-04 00:12:52 INFO     192.168.1.112 - - [04/Jun/2023 00:12:52] "POST /socket.io/?EIO=4&transport=polli ng&t=OY4cvKR&sid=rTkwyevVy-z9BylTAAAM HTTP/1.1" 200 -
2023-06-04 00:13:17 INFO     192.168.1.112 - - [04/Jun/2023 00:13:17] "GET /socket.io/?EIO=4&transport=pollin g&t=OY4cvKS&sid=rTkwyevVy-z9BylTAAAM HTTP/1.1" 200 -
2023-06-04 00:13:17 INFO     192.168.1.112 - - [04/Jun/2023 00:13:17] "POST /socket.io/?EIO=4&transport=polli ng&t=OY4c_SR&sid=rTkwyevVy-z9BylTAAAM HTTP/1.1" 200 -
2023-06-04 00:06:21 INFO     Started pool-pi.py
2023-06-04 00:06:21 WARNING  Werkzeug appears to be used in a production deployment. Consider switching to a  production web server instead.
2023-06-04 00:06:21 INFO      * Running on http://0.0.0.0:5000/ (Press CTRL+C to quit)
pi@pi:~ $ tail /home/pi/Pool-Pi/logs/pool-pi.log
    return getattr(self, '_upgrade_' + transport)(environ,
  File "/usr/local/lib/python3.9/dist-packages/engineio/socket.py", line 158, in _upgrade_websocket
    return ws(environ, start_response)
  File "/usr/local/lib/python3.9/dist-packages/engineio/async_drivers/threading.py", line 22, in __call__
    self.ws = Server(environ)
  File "/usr/local/lib/python3.9/dist-packages/simple_websocket/ws.py", line 319, in __init__
    raise RuntimeError('Cannot obtain socket from WSGI environment.')
RuntimeError: Cannot obtain socket from WSGI environment.
2023-06-04 10:26:14 INFO     192.168.1.112 - - [04/Jun/2023 10:26:14] "GET /socket.io/?EIO=4&transport=pollin g&t=OY6pCCq&sid=_dYI8eg7hPCRQQUxAAAA HTTP/1.1" 200 -
2023-06-04 10:26:14 INFO     192.168.1.112 - - [04/Jun/2023 10:26:14] "POST /socket.io/?EIO=4&transport=polli ng&t=OY6pI6X&sid=_dYI8eg7hPCRQQUxAAAA HTTP/1.1" 200 -
pi@pi:~ $

ChaseDurand, 2023-06-04:
Hello! Thank you for reporting this issue.

The error says that "serial0" is not defined in model.py line 104, and says "self.ser = serial0.Serial0(". Is this a change from the original code? I show the following:
```python
        self.ser = serial.Serial(
            port="/dev/ttyAMA0",
            baudrate=19200,
            parity=serial.PARITY_NONE,
            stopbits=serial.STOPBITS_TWO,
        )
```

Another user reported that they had to change "ttyAMA0" to "serial0", but I'm not sure if anything else needs to be modified.

If you made changes to the code, would you mind sharing them so I can try to help?

Thanks!

cwalker1960, 2023-06-07:
yes i did change those trying to get past the no attribute for serial, I've changed things back and forth many times now so hard to remember what worked , I know at first it would display a web page but it always said waiting for pi  to connect, then after changing some of the things  in serial , it finally started showing  the pool stautus in the log files things like pool temp , salt level, pool on, etc, but then it wouldn't load a web page,, I'm wiping the sd card for about the 10th time now and starting from scratch and i will record each log file and report what changes was made each time. and yeas I also followed (Rich?)s instructions from start to see if that worked ,, just changing ttyAMA0 to serial0 didn't fix the serial has no attribute problem for me. I remember it was when i  pip3 uninstall serial was when it finally started getting data from the pool controller and thats when it would no longer open a web page , it would just say this site isn't responding or cant be reached or something to that effect ,, anyhow like i said starting from scratch and this time I'll record each change., And thank you very much for the help and the program. I do hope i can get it working. the display on my panel quit , panel still works but i can't tell what i'm  doing,

cwalker1960, 2023-06-07:
sorry added this . checking the status of poolpi at the end it says attribute error module serial has no attribute
login as: pi
pi@pi's password:
Linux pi 6.1.21+ #1642 Mon Apr  3 17:19:14 BST 2023 armv6l

The programs included with the Debian GNU/Linux system are free software;
the exact distribution terms for each program are described in the
individual files in /usr/share/doc/*/copyright.
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
cwalker1960, 2023-06-10:
I know you didn't post this for people to aggravate you with it and I'm sorry that I'm the one doing it but all i can figure is something has been changed in the dependencies that is causing the attribute error. I know I have followed the install instructions to the letter and i have followed everything I can find on the internet as to how to clear it up with no success.

ChaseDurand, 2023-06-10:
Hi cwalker. My apologies for just now getting back to you.

I believe the issue was that the python packages in requirements.txt included "serial" and not "pyserial". "pyserial" is the correct package- even though it is imported in the code as "serial". I believe the reason this went unnoticed on my end is because I had likely manually installed pyserial while developing pool-pi and then retroactively created the requirements file for the ease of others. "pip3 list" showed both serial and pyserial packages installed on my raspberry pi. Uninstalling all packages and installing with the original requirements file resulted in the same AttributeError you saw. Correcting the requirements file from serial to pyserial and reinstalling seems to have resolved that issue.

I have corrected the requirements file with commit cd9d96d. Please let me know if this works for you!

cwalker1960, 2023-06-11:
Chase,
Thank you, thank you, thank you,, everything is working except the filter button. that just puts it in a waiting loop and i have to stop and restart the service. I'll work on that myself and try not to bother you with it. i don't know if it inherited my panel layout or not but all the buttons are even labeled properly.

ChaseDurand, 2023-06-11:
Awesome! I'm glad it's up and running. Would you mind sharing a picture of your hardware setup for my own curiosity?

The auxiliary buttons are labeled for my own setup and I unfortunately haven't implemented a simple way to modify them (ex change AUX5 to fountain or something).

Concerning the filter button, I'm not sure why it's not working but I'd like to fix it if possible. Do you have a multi speed pump?

Thank you for all the details you've provided throughout the debug process.

cwalker1960, 2023-06-12:
My hardware setup? HaHa, Surely you are joking me? There's the photos i do intend to mount it all in a box now that it's working.
Also i was in a hurry the other day and i thought everything was
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

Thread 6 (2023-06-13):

help with commands py

cwalker1960, 2023-06-13:
Before you put any effort into this let me connect everything at the pool panel so they will all have a common ground just in case that is the issue. I feel like that not the problem since some things work but who knows , best to make sure. I 'll try to work on that tomorrow and let you know how it goes
I'm going to attach the log file where i turned on things from the panel
I've noted the lines that depict what i turned off and on
1) lights starts at line 51316 indicates they are working but they don't activate the relays, does  works on outside panel
2)spa light  line 51345 same as pool light
3)cleaner 51374 locks up system when activated from web ui
4) filter pump 51406 it appears to send multiple lines , locks up system when activated from web ui
5) waterfall 51457 it's on aux 4 and it works as it should
6) heater 51500 and it locks up the system when activated from web ui same as the filter pump and the cleaner
i didn't note the spa blower but it works as it should

*** new ******
you had
"filter": b"\x00\x80\x00\x00",
from  the log my panel sends
"filter": b"\x80\x00\x00\x00",
so I changed it in the command file , rebooted and now the filter pump works as it should and strangely enough so does the pool light, spa light still a no go and the cleaner locks up the system with interlock prevents turn on, which I was half way expecting .

Closed 2023-06-13.

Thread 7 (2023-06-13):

Not an issue just easy setup instructions to hopefully help others

cwalker1960, 2023-06-13:
Easy setup for Pool-Pi
quick commands;
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

** notes q ends loop and gets you back to a pi prompt
*** always use nano to edit a file vi has way to many commands just to exit, control x gets you out of nano

**EasySetup step by step guide **

1)download IM-Magic partition resizer free
2)download Raspberry Pi imager
3)start IM Magic and delete all partitions ON SD CARD, not your hard drive, create 1 fat32 partition, and format disk, click the check to perform all operations.
4) open R Pi imager, choose the recommended bullseye with desktop, choose your sd card you formatted,
5)open settings,hostname "pi.local",,
6)use password authentication checked, set username "pi" ..7)set password to whatever you like.
8)check configure wireless lan and enter your network information,
9)set your country and timezone and click save, then click write.
10)once its finished you should be able to start your pi zero with it
11) install and open putty on whatever computer your using, in hostname type pi and click open, login as pi and enter your password
12) once at a prompt enter :
>$ sudo apt get update " once thats finished enter;
>$ sudo apt get upgrade " ^^^^^^^^^^^^^^^^^^^^^^^^ ;
>$ sudo raspi-config "    ^^^^^^^^^^^^^^^^^^^^^^^^;
*scroll down to interface options, scroll down to serial port, answer no to login shell over serial and yes to serial hardware and finish
*next we need to disable bluetooth in order to use ttyAMA0 as our serial port
>$ sudo nano /boot/config.txt "
*scroll to the bottom of the file , copy and paste this line
dtoverlay=disable-bt

hit control x then y then enter ,,,,
next enter;
>$ sudo systemctl disable hciuart "
* Set Static IP
>$ hostname -I " write down your pi current ip address
>$ ip r | grep default   " write down your gateway address ,this is your router dns
>$ sudo nano /etc/dhcpcd.conf
* scroll to the bottom of the file and copy and paste these 4 lines making sure to change the static ip to your rpi address and router and dns to your routers address

interface wlan0
static ip_address=192.168.1.252/24
static routers=192.168.1.1
static domain_name_servers=192.168.1.1

* make ssh key for github
enter;
>$  ssh-keygen -t ed25519 -C "your_email@example.com"  ### ///make sure to replace with your email that you use for your github account then just click enter to write it to the directory it lists , add a password if you like or just click enter twice then enter
>$ cat < ~/.ssh/id_ed25519.pub "
highlight the output by dragging left mouse click over it then right click it to copy to clipboard, go to github, sign in, and paste the ssh key to your account

* get  Pool-Pi program
>$  git clone --depth 1 git@github.com:ChaseDurand/Pool-Pi.git
* Run setup.sh to install and configure systemd to run pool-pi.py on startup.
 >$   sudo /home/pi/Pool-Pi/setup/setup.sh
* Confirm the status of the service.
 > $ systemctl status poolpi.service
      * Confirm log file creation.
 >$   tail /home/pi/Pool-Pi/logs/pool-pi.log
 you should be able to see your work by opening a browser and typing your rpi ip address in the in the address bar plus :5000 at the end  example 192.168.1.252:5000 is mine
* Complete the hardware setup as outlined in the Pool-Pi docs file
** if all went well you should have at the very least a partially working system at this point
I will detail how to change any settings in the commands py file as soon as I figure it all out myself

Closed 2023-06-13.

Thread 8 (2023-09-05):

Commands not working

mhmatttu, 2023-09-05:
Good evening.  My setup is using a raspberry pi 2b and all other recommended hardware and connections.  My panel is an aqualogic on main software revision 2.85.  Appears to be the same panel as @ChaseDurand. I also have the AQL-TTW-RF-PS-8 remote.

I am able to see all display and LED status updates in real time from the web browser UI. Unfortunately I am unable to get commands to work.  Some buttons in the UI (i.e menu) do nothing.  Others (i.e lights) result in the loading gif and have to restart the program.

On one occassion, the filter button did seem to work in the UI but the system went into service timeout mode and was unable to cancel service mode using the service button

I have reviewed all of the documents, open/closed issues, the blog at Desert Home, and swilson aqualogic info.  I made many changes to the commands.py and model.py files following recommendations on these sites, but none have worked yet.

Any ideas on troubleshootng are greatly appreciated.  Thank you.

ChaseDurand, 2023-09-12:
Hi mhmatttu. My apologies on the delay and I'm sorry to hear something isn't working.

I'm on main software revision 2.86 so I wouldn't expect any discrepancies there. I don't think there should be any differences with the RPi 2b vs Zero W for the UART and GPIO used here but will double check.

If you're able to read commands but not send any, I'm thinking there could be a problem with the wiring related to your RS485 adapter's Drive/Receive Enable. Revising my [diagram](https://github.com/ChaseDurand/Pool-Pi/blob/master/docs/media/wiring_2.png), I don't think I made things very clear: DE and ~RE are both tied together to the pull down resistor and pin 11 (GPIO 17); the orange net shown does not connect to pin 12 (GPIO 18). What RS485 adapter do you have? Can you share pictures of your setup?

Just another variable that I'm not sure would cause an issue, but could you try sending commands while the AQL-BASE-RF (or equivalent panel side wireless base station for your AQL-TTW-RF-PS-8) is disconnected?

Let me know if either of these ideas help.

Thank you.

mhmatttu, 2023-09-12:
Hi Chase.  No worries...I appreciate the response and help!

Here is the RS485 adapter I am using from [Amazon](https://a.co/d/2PYTVgU).  I'm fairly confident I have the wiring correct with DE and ~RE tied together with the 1k resistor connected to pin 11.  This is a friend's pool but I will grab a picture the next time I'm over there (this weekend or sooner).  Will also try some commands with the AQL-TTW-RF-PS-8 disconneted.  Should this be simply unplugged from power or unplugged from the panel main board?

mhmatttu, 2023-09-13:
Quick follow-up.  I unplugged the AQL-TTW-RF-PS-8 and confirmed there was no activity in the logs from that device.

I've attempted various command structures with no success.  I even attempted to to use the wireless remote command structure following the Desert Home blog.  Below is a screenshot of a light command attempt

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

I have tried all frame types with no luck.  I've also tried using the swilson HA code with various modications with no luck.  In all scenarios I can conistently get sensor, LED and display data accurately and real time.  Just no luck with commands.

mhmatttu, 2023-09-14:
As a last ditch effort, I decided to try a USB rs485 [converter ](https://a.co/d/b8nDyh9 )connected to another project. To my suprise, it works!  I had double checked the wiring multiple times and tried a couple of the other converters...not sure why it wasnt working.

some commands seem to time out which freezes the application requiring a restart of the service.   I may start from scratch and see if I have better luck.  Thank you!

ChaseDurand, 2023-09-14:
Glad to hear the new serial adapter works!

Does the application unfreeze after the max send attempts is reached? You can try lowering [MAX_SEND_ATTEMPTS](https://github.com/ChaseDurand/Pool-Pi/blob/cd9d96d88bbc2f1d1d0c84a4f3416a47448a5293/src/commands.py#L1) to check, but if the command fails the loading GIF should disappear and the GUI should become responsive again.

mhmatttu, 2023-09-15:
Thanks!  For the commands that are not working (i.e service), the loading GIF continues enlessly unless I force stop the service and restart.  Today I noticed that the panel seemed to recieve the service command and go into service mode but the LED on the GUI did not light and it stuck in the loading screen.  When watching the logs, I can see all 10 attempts, then the error message, but it does not become responsive again.

I was only able to get my panel to respond to the wireless remote command x00x83 and had to modify line 166 of model.py to: DLE + STX + FRAME_TYPE_LOCAL_TOGGLE + b"\x01" + commandData + commandData + b"\x00".

For menu, I have to press multple times to cycle the next menu.  Same for the arrow and + buttons.  The minus button does not  respond but also does not freeze the GUI.

Closed 2023-09-14.

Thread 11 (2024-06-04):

Integration into Home Assistant?

blulite, 2024-06-04:
This is GREAT stuff, thanks!   Is there any development still going on with this project?   I am connecting this solution to Home Assistant as it is the most reliable solution (putting the PI/serial connection by the pool instead of remote Serial-IP stuff).

I've coded some MQTT into the Python code to get the status to HA, and that is working.    I am developing communication so that HA can switch on/off pool resources).   Where is the best place to turn things on and off?   I can subscribe to the MQTT topic and turn it on/off in Python, but I thought it might be interesting to make an HTTP call directly from HA (HTTP://poolpi:5000/lights_on).  I only follow some Java stuff, but I thought I would ask before I try to figure it out.

Jeff

ChaseDurand, 2024-06-06:
Hi Jeff! Thank you for the kind words and your interest. While there is no active development, my system has been running without issue on the side of my home. Further improvements I'd like to make but don't have any schedule for are easier customization of auxiliary names, support for variable speed pumps, and support for older P-4 remotes.

I'm away from my computer so any code I write below is untested, but I think the easiest way to get HA talking back to the controller is to have HA push commands to MQTT and read them in src/pool-pi.py [getCommand](https://github.com/ChaseDurand/Pool-Pi/blob/b03dc3ecf949ea96c76bac310882ec95682d622f/src/pool-pi.py#L175). Right now this is done with a Redis server which takes messages from the web interface but it should work the same with MQTT. The commands are json with the resource id and modelVersion to ensure the user-facing state and actual state of the system are in sync. I've never used MQTT but I think it would be straightforward to send a message with those two values from HA and subscribe+parse them here in python.

For the HTTP endpoint approach, I think you would modify src/web.py to add in the api routes and then publish the command to the Redis server to be parsed in getCommand. If the JSON in your POST from HA matches what getCommand expects, you could pass it through like this:

```python
@app.route('/api', methods=['POST'])
def HACommand():
    r.publish("inbox", request.get_json())
    return "", 204
```

or individually by command:

```python
@app.route('/api/lights', methods=['POST'])
def HACommandLights():
    modelVersion = request.get_json()
    #form message with id and modelVersion
    message = "{ 'id': lights, 'modelVersion': "+ modelVersion + " }"
    r.publish("inbox", json.dumps(message))
    return "", 204
```

and then repeated for all commands. I'm not sure the advantage the second option gives you with this situation considering all of my command messages follow the same form.

Another note is that all of the commands (except menu buttons) sent over RS485 to the OEM board act as toggles. If you want to explicitly turn the lights off, you can't send a "lights off" command, so you have to check the state of the lights to figure out if you need to send a command or not, and similarly check the state after sending a command to ensure it went through (and didn't have a collision on the RS485 bus) before sending an additional attempt (I already handle this). If you want to have a lights off command then the easiest way would be to implement the logic in HA to check if the current state matches, and send a toggle command if not.

I found a subset of commands from an older controller that do support separate on/off packets, so you can send without needing to check the state of the system or worry about accidentally sending two messages, but I don't use them in my code: [Legacy On/Off Commands](https://github.com/ChaseDurand/Pool-Pi/blob/master/docs/PROTOCOL_NOTES.md#legacy-onoff-commands).

I should add that I don't know anything about API design, am away from a development machine, and am shooting from the hip with all of this.

Let me know if there is any other info I can provide!
Chase

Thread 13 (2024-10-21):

Heater Button (no confirmation needed) GUI stalls

tammycutzet, 2024-10-21:
Hello,

after the successful installation of pool-pi (Thanks for the great work!), i have one problem that I couldnt solve yet. Everything came up as expected, just the assignment of functions for the AUX relays was a bit different at my pool.

The issue I currently have is with the Filter and Heater1 button. These buttons do not turn on/off the components, they are showing a different menu. From my understanding they are more handled as menu buttons.

When I press the Heater1 button, the display shows the Heater1 status. Also i get the loading gif that will not go away anymore.

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

I checked thru the code a little bit, and I assume that the Button Heater1 and Filter will not receive a confirmation as for example the Spa Light. When I move the Heater1 button from button_toggle to buttons_menu, the system stalls as quickly as it tries to update the LED for Heater1

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

Can somebody maybe point me to the right direction on how I can realize this? Im not super experienced in coding yet.

tammycutzet, 2024-10-23:
I made another observation. When I press the filter button the command received by the controller is Aux 12

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

I tried around to find the right value for this command, but without success right now. Does anyone know which is the right command?

ChaseDurand, 2024-10-23:
Hello,

Sorry I haven't had time to look into this yet. What model heater and pump do you have? And which model Hayward/Aqualogic system do you have?

Thank you.

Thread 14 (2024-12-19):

Will not install

TheBobC, 2024-12-19:
Trying to install this on PI 3. I get all the way to the important part...  "sudo /home/pi/Pool-Pi/setup/setup.sh"   and this is the result. Any guidance?

pi@raspberrypi:~ $   sudo /home/pi/Pool-Pi/setup/setup.sh
sudo: unknown user 1000
sudo: error initializing audit plugin sudoers_audit
sudo: unknown user 1000
sudo: error initializing audit plugin sudoers_audit
sudo: unknown user 1000
sudo: error initializing audit plugin sudoers_audit
sudo: unknown user 1000
sudo: error initializing audit plugin sudoers_audit
sudo: unknown user 1000
sudo: error initializing audit plugin sudoers_audit
sudo: unknown user 1000
sudo: error initializing audit plugin sudoers_audit
sudo: unknown user 1000
sudo: error initializing audit plugin sudoers_audit
sudo: unknown user 1000
sudo: error initializing audit plugin sudoers_audit
sudo: unknown user 1000
sudo: error initializing audit plugin sudoers_audit
cp: cannot stat '/setup/poolpi.service': No such file or directory
chmod: cannot access '/etc/systemd/system/poolpi.service': No such file or directory
Synchronizing state of redis-server.service with SysV service script with /lib/systemd/systemd-sysv-install.
Executing: /lib/systemd/systemd-sysv-install enable redis-server
Failed to enable unit: Unit file poolpi.service does not exist.
sudo: unknown user 1000
sudo: error initializing audit plugin sudoers_audit
pi@raspberrypi:~ $

TheBobC, 2024-12-19:
By the way, I did try the things you suggested to tammycutzet on the closed issue that was the same as mine. Results are below. I am unclear what she did to fix

pi@raspberrypi:~ $ sudo touch test
pi@raspberrypi:~ $ ls
Pool-Pi  test
pi@raspberrypi:~ $ id
uid=1000(pi) gid=1000(pi) groups=1000(pi),4(adm),20(dialout),24(cdrom),27(sudo),29(audio),44(video),46(plugdev),60(games),100(users),102(input),105(render),110(netdev),993(gpio),994(i2c),995(spi)
pi@raspberrypi:~ $ sudo -i
root@raspberrypi:~# echo $SUDO_UID
1000
root@raspberrypi:~# exit
logout
pi@raspberrypi:~ $

ChaseDurand, 2024-12-28:
Hi Bob,

My apologies for the delay. I've corrected the startup script in commit 5d0faea. Would you mind confirming it works for you?

Thank you

TheBobC, 2024-12-28:
Thank you for looking in to it. Now I do get a step further, but this is the error I get on setup:

poolpi@raspberrypi:~ $ sudo /home/poolpi/Pool-Pi/setup/setup.sh
Setting up pool-pi.
Installing venv.
error: externally-managed-environment

× This environment is externally managed
╰─> To install Python packages system-wide, try apt install
    python3-xyz, where xyz is the package you are trying to
    install.

    If you wish to install a non-Debian-packaged Python package,
    create a virtual environment using python3 -m venv path/to/venv.
    Then use path/to/venv/bin/python and path/to/venv/bin/pip. Make
    sure you have python3-full installed.

    For more information visit http://rptl.io/venv

note: If you believe this is a mistake, please contact your Python installation or OS distribution provider. You can override this, at the risk of breaking your Python installation or OS, by passing --break-system-packages.
hint: See PEP 668 for the detailed specification.
poolpi@raspberrypi:~ $

TheBobC, 2024-12-28:
I did try installing python3-full but that made no difference

ChaseDurand, 2024-12-28:
I'm looking into this. Can you please run both
- `cat /etc/os-release`
- `python --version `

Thank you

TheBobC, 2024-12-28:
Sure thing...here you go

poolpi@raspberrypi:~ $ cat /etc/os-release
PRETTY_NAME="Debian GNU/Linux 12 (bookworm)"
NAME="Debian GNU/Linux"
VERSION_ID="12"
VERSION="12 (bookworm)"
VERSION_CODENAME=bookworm
ID=debian
HOME_URL="https://www.debian.org/"
SUPPORT_URL="https://www.debian.org/support"
BUG_REPORT_URL="https://bugs.debian.org/"
poolpi@raspberrypi:~ $ python --version
Python 3.11.2
poolpi@raspberrypi:~ $

ChaseDurand, 2024-12-29:
Thank you. I'm on Linux 12 (bullseye) and python 3.9. I will upgrade to verify my changes fix the issue, but please try the most recent commit 3539274

TheBobC, 2024-12-29:
Thank you for keeping after it. Tried it with the most recent commit and got the same results.

ChaseDurand, 2024-12-29:
Some other checks:
Would you mind running
-`which python` and
-`sudo apt install python3-venv` (same command in script just outside the script) and
-`sudo apt install python3.11-venv`(specifying python version)

Thank you.

TheBobC, 2024-12-29:
Here you go:
poolpi@raspberrypi:~ $ which python
/usr/bin/python
poolpi@raspberrypi:~ $ sudo apt install python3-venv
Reading package lists... Done
Building dependency tree... Done
Reading state information... Done
python3-venv is already the newest version (3.11.2-1+b1).
0 upgraded, 0 newly installed, 0 to remove and 0 not upgraded.
poolpi@raspberrypi:~ $ sudo apt install python3.11-venv
Reading package lists... Done
Building dependency tree... Done
Reading state information... Done
python3.11-venv is already the newest version (3.11.2-6+deb12u4).
python3.11-venv set to manually installed.
0 upgraded, 0 newly installed, 0 to remove and 0 not upgraded.
poolpi@raspberrypi:~ $

jojopi, 2025-01-07:
> sudo: unknown user 1000

The problem is that `sudo -u` expects a username, not a bare uid.

setup.sh should be using `$SUDO_USER` instead of `$SUDO_UID`.

kkabza, 2025-01-15:
I also hit the × This environment is externally managed
╰─> To install Python packages system-wide, try apt install
python3-xyz, where xyz is the package you are trying to
install.

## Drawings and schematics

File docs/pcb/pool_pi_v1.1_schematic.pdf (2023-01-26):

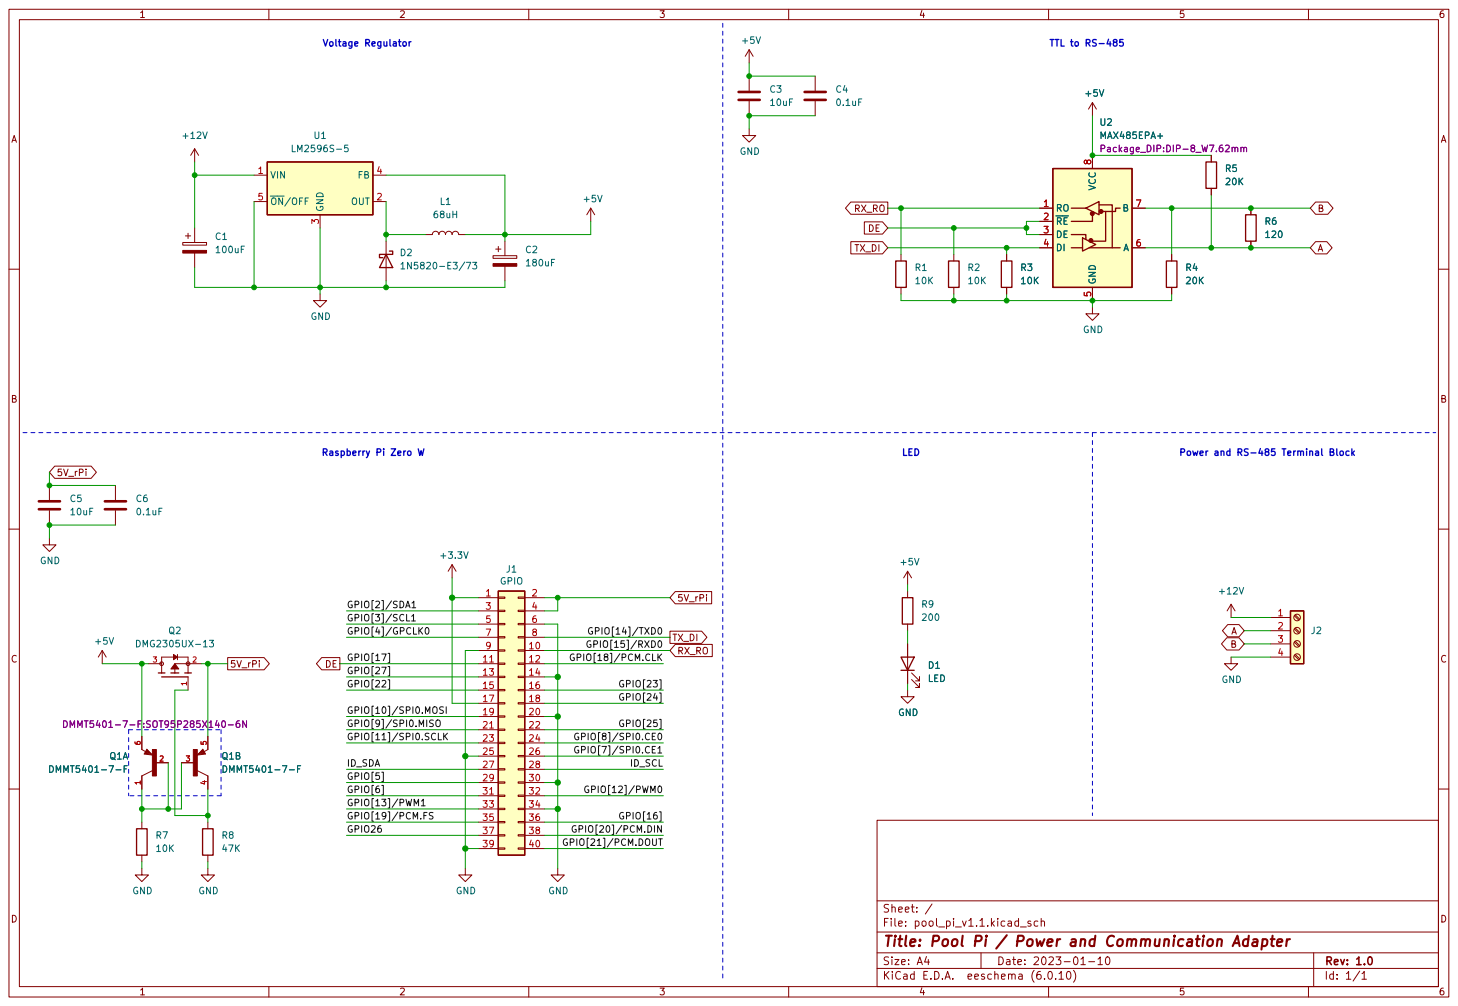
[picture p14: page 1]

Id: 1/1 Title: Pool Pi / Power and Communication Adapter

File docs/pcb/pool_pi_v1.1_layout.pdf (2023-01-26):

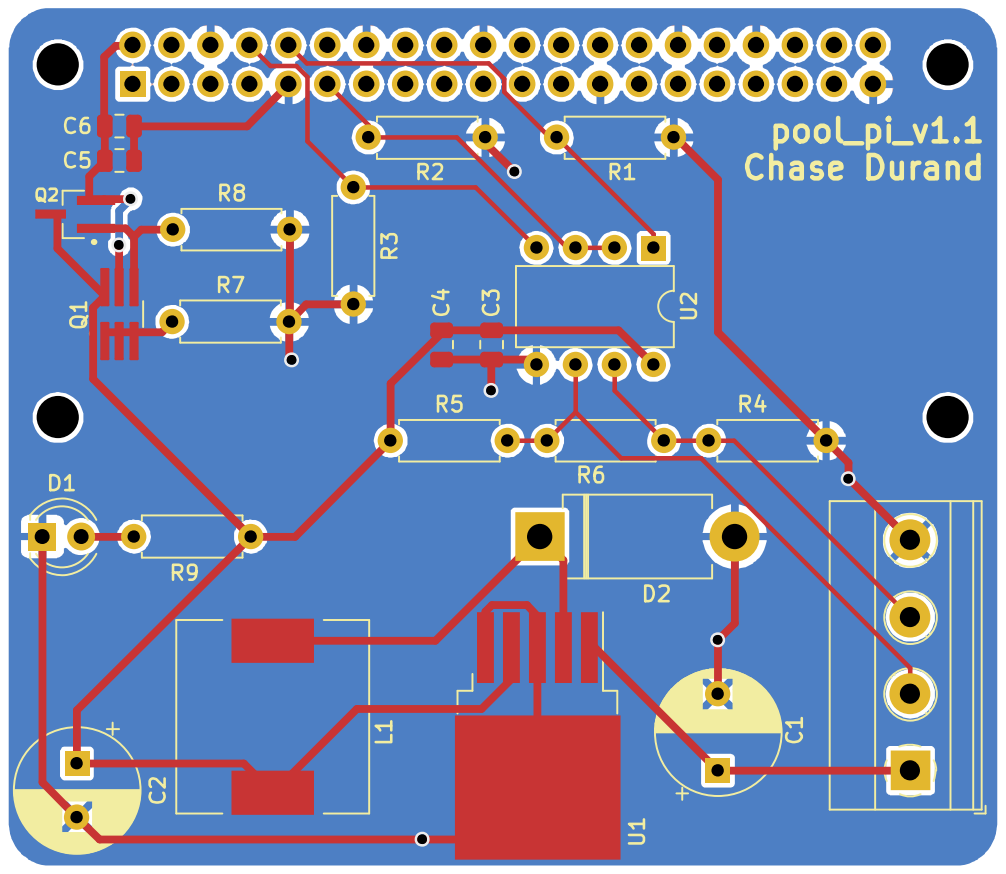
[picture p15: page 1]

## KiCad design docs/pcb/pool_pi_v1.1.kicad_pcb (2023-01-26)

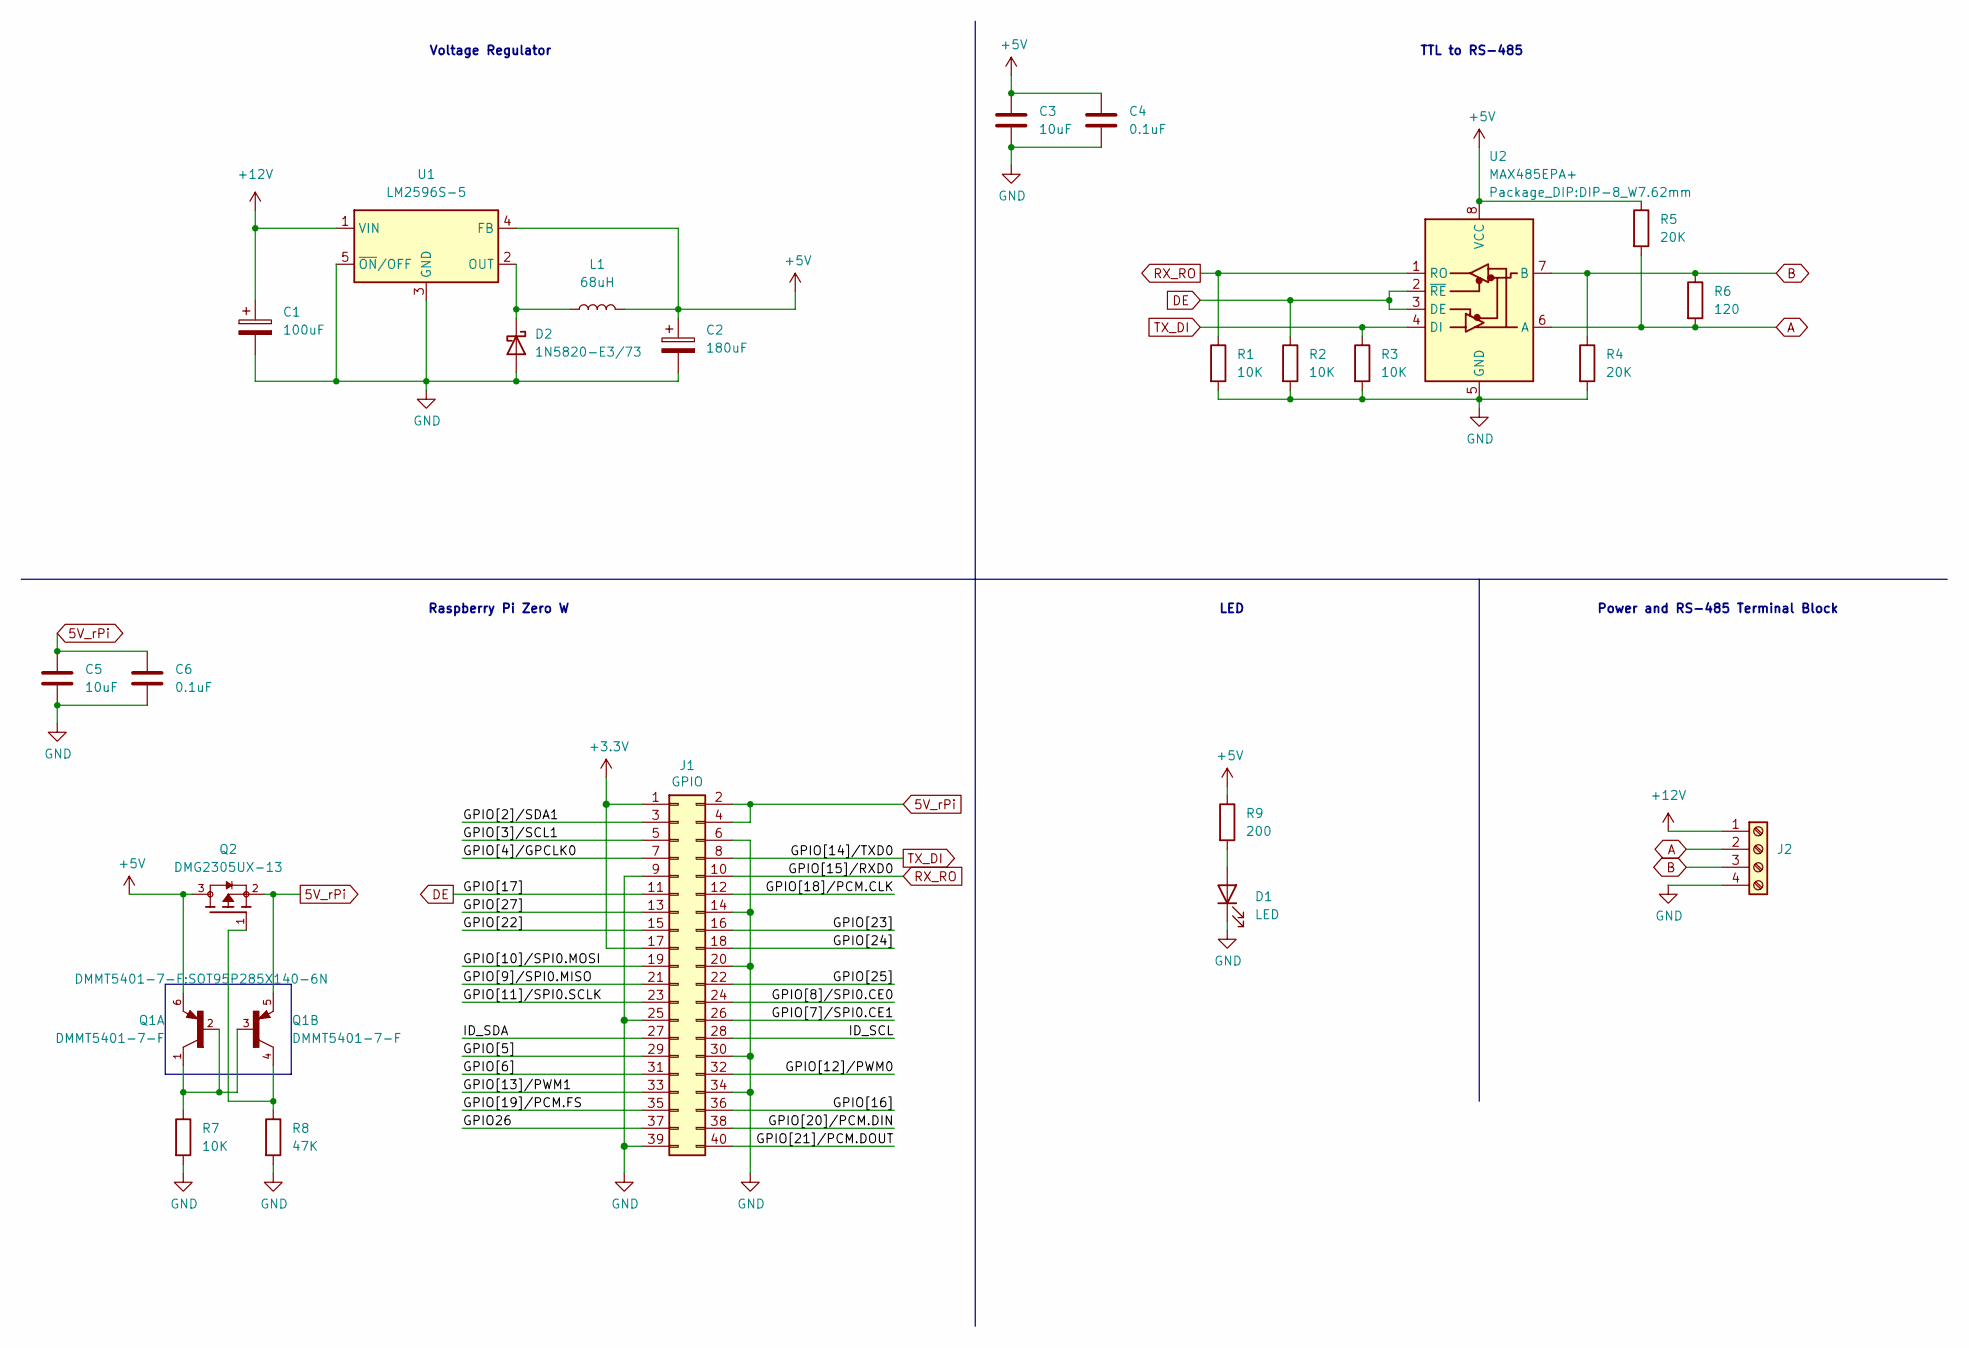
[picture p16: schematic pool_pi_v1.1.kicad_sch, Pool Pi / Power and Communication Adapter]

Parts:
C1: 100uF; CP_Radial_D8.0mm_P5.00mm; Part EEU-FR1H101B
C2: 180uF; CP_Radial_D8.0mm_P3.50mm; Part EEU-FR1V181
C3, C5: 10uF; C_0805_2012Metric; Part C0805C106K8PAC
C4, C6: 0.1uF; C_0805_2012Metric; Part C0805C104M5RACTU
D1: LED; LED_D4.0mm; Part C4SMA-GGY-CU2W37A1
D2: 1N5820-E3/73; D_DO-201AD_P12.70mm_Horizontal
J1: GPIO; PinSocket_2x20_P2.54mm_Vertical
J2: 1711042; TerminalBlock_Phoenix_MKDS-1,5-4_1x04_P5.00mm_Horizontal
L1: 68uH; L_12x12mm_H8mm; Part MSS1278H-683KED
Q1: DMMT5401-7-F; SOT95P285X140-6N; PARTREV 8
Q2: DMG2305UX-13; SOT91P240X110-3N; PARTREV 09/2018
R1, R2, R3, R7: 10K; R_Axial_DIN0207_L6.3mm_D2.5mm_P7.62mm_Horizontal; Part CCF0710K0JKE36
R4, R5: 20K; R_Axial_DIN0207_L6.3mm_D2.5mm_P7.62mm_Horizontal; Part CCF0720K0JKE36
R6: 120; R_Axial_DIN0207_L6.3mm_D2.5mm_P7.62mm_Horizontal; Part CCF07120RGKE36
R8: 47K; R_Axial_DIN0207_L6.3mm_D2.5mm_P7.62mm_Horizontal; Part CCF0747K0JKE36
R9: 200; R_Axial_DIN0207_L6.3mm_D2.5mm_P7.62mm_Horizontal; Part CCF07200RGKE36
U1: LM2596S-5; TO-263-5_TabPin3
U2: MAX485EPA+; DIP-8_W7.62mm

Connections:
5V_rPi: C5.1, C6.1, J1.2, J1.4, Q1.5, Q2.2
+3V3: J1.1, J1.17
+5V: C2.1, C3.1, C4.1, L1.2, Q1.6, Q2.3, R5.1, R9.1, U1.4 (FB), U2.8 (VCC)
+12V: C1.1, J2.1, U1.1 (VIN)
/GPIO26: J1.37
/GPIO[2]/SDA1: J1.3
/GPIO[3]/SCL1: J1.5
/GPIO[4]/GPCLK0: J1.7
/GPIO[5]: J1.29
/GPIO[6]: J1.31
/GPIO[7]/SPI0.CE1: J1.26
/GPIO[8]/SPI0.CE0: J1.24
/GPIO[9]/SPI0.MISO: J1.21
/GPIO[10]/SPI0.MOSI: J1.19
/GPIO[11]/SPI0.SCLK: J1.23
/GPIO[12]/PWM0: J1.32
/GPIO[13]/PWM1: J1.33
/GPIO[16]: J1.36
/GPIO[18]/PCM.CLK: J1.12
/GPIO[19]/PCM.FS: J1.35
/GPIO[20]/PCM.DIN: J1.38
/GPIO[21]/PCM.DOUT: J1.40
/GPIO[22]: J1.15
/GPIO[23]: J1.16
/GPIO[24]: J1.18
/GPIO[25]: J1.22
/GPIO[27]: J1.13
/ID_SCL: J1.28
/ID_SDA: J1.27
A: J2.2, R5.2, R6.2, U2.6 (A)
B: J2.3, R4.1, R6.1, U2.7 (B)
DE: J1.11, R2.1, U2.2 (~RE), U2.3 (DE)
GND: C1.2, C2.2, C3.2, C4.2, C5.2, C6.2, D1.1 (K), D2.2 (A), J1.6, J1.9, J1.14, J1.20, J1.25, J1.30, J1.34, J1.39, J2.4, R1.2, R2.2, R3.2, R4.2, R7.2, R8.2, U1.3 (GND), U1.5 (~ON/OFF), U2.5 (GND)
unnamed: D1.2 (A), R9.2
unnamed: D2.1 (K), L1.1, U1.2 (OUT)
unnamed: Q1.1, Q1.2, Q1.3, R7.1
unnamed: Q1.4, Q2.1, R8.1
RX_RO: J1.10, R1.1, U2.1 (RO)
TX_DI: J1.8, R3.1, U2.4 (DI)

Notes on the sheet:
Power and RS-485 Terminal Block
LED
TTL to RS-485
Raspberry Pi Zero W
Voltage Regulator

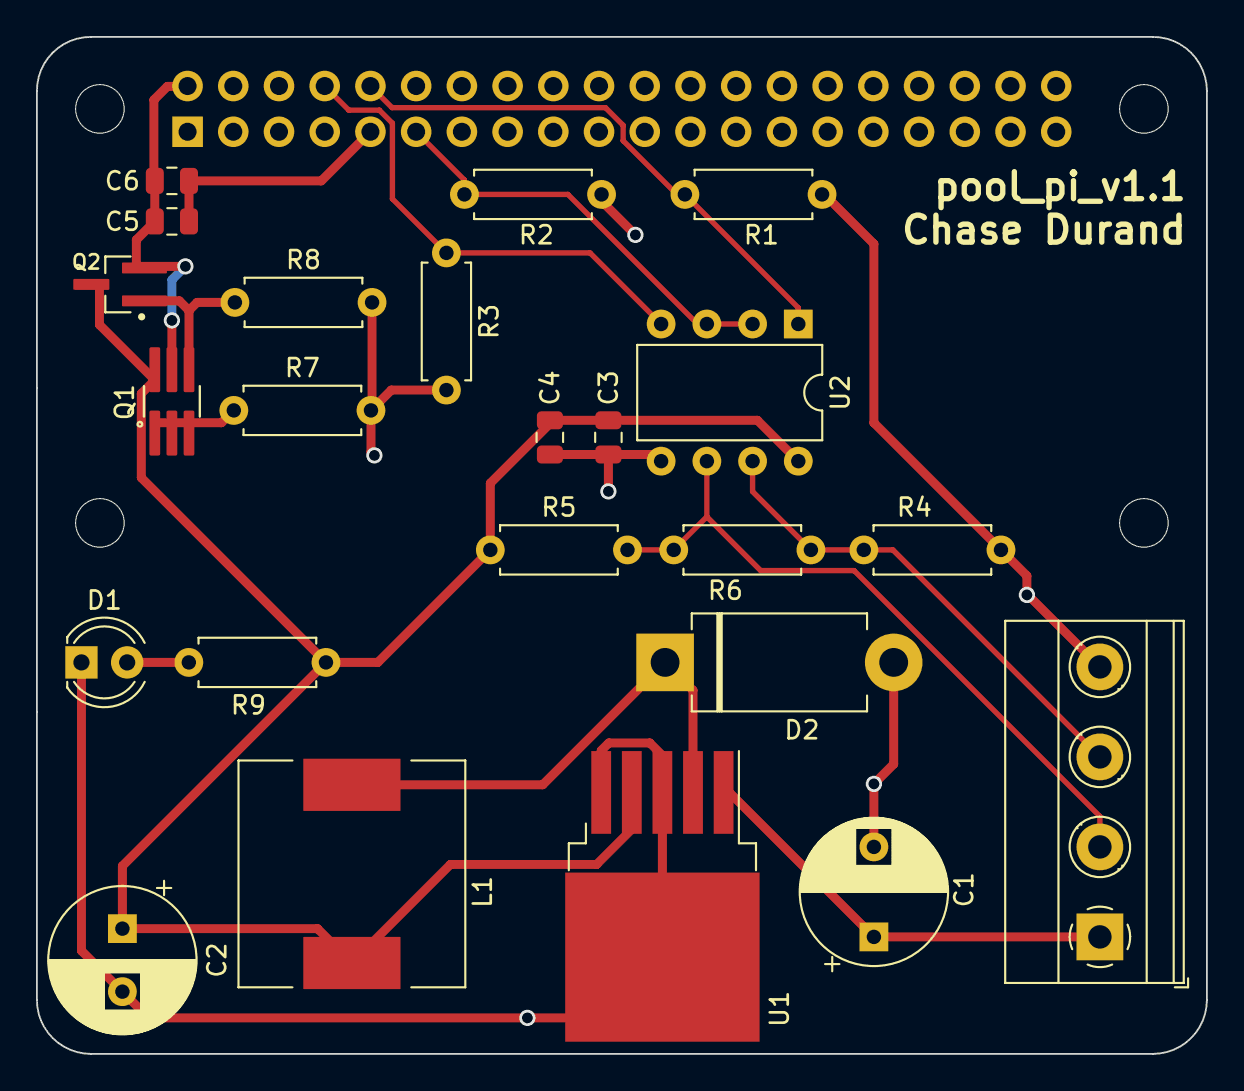
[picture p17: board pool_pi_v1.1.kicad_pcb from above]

Board: 2 copper layers, 65.0 x 56.5 mm, 28 parts (1 on the bottom side), 14 nets.

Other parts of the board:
MH1, MH2, MH3, MH4: MountingHole_2.7mm_M2.5

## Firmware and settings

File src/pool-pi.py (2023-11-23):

from distutils.log import INFO
from commands import *
from threading import Thread
from model import *
from web import *
from parsing import *
from os import makedirs
from os.path import exists
import logging
from logging.handlers import TimedRotatingFileHandler

socketio = SocketIO(message_queue="redis://127.0.0.1:6379")
r = redis.Redis(charset="utf-8", decode_responses=True)
pubsub = r.pubsub()
pubsub.subscribe("inbox")


def readSerialBus(serialHandler):
    """
    Read data from the serial bus to build full frame in buffer.
    Serial frames begin with DLE STX and terminate with DLE ETX.
    With the exception of searching for the two start bytes,
    this function only reads one byte to prevent blocking other processes.
    When looking for start of frame, looking_for_start is True.
    When buffer is filled with a full frame and ready to be parseed,
    buffer_full is set to True to signal parseBuffer.
    """
    if serialHandler.in_waiting() == 0:  # Check if we have serial data to read
        return
    if (
        serialHandler.buffer_full == True
    ):  # Check if we already have a full frame in buffer
        return
    serChar = serialHandler.read()
    if serialHandler.looking_for_start:
        # We are looking for DLE STX to find beginning of frame
        if serChar == DLE:
            serChar = serialHandler.read()
            if serChar == STX:
                # We have found start (DLE STX)
                serialHandler.buffer.clear()
                serialHandler.buffer += DLE
                serialHandler.buffer += STX
                serialHandler.looking_for_start = False
                return
            else:
                # We have found DLE but not DLE STX
                return
        else:
            # Non-DLE character
            # We are only interested in DLE to find potential start
            return
    else:
        # We have already found the start of the frame
        # We are adding to buffer while looking for DLE ETX
        serialHandler.buffer += serChar
        # Check if we have found DLE ETX
        if (serChar == ETX) and (
            serialHandler.buffer[-2] == int.from_bytes(DLE, "big")
        ):
            # We have found a full frame
            serialHandler.buffer_full = True
            serialHandler.looking_for_start = True
            return


def parseBuffer(poolModel, serialHandler, commandHandler):
    """
    Check if we have full frame in buffer.
    If we have a full frame in buffer, parse it.
    If frame is keep alive, check to see if we are ready to send a command and if so send it.
    """
    if serialHandler.buffer_full:
        frame = serialHandler.buffer
        # Remove any extra x00 after x10
        frame = frame.replace(b"\x10\x00", b"\x10")

        # Ensure no erroneous start/stop within frame
        if b"\x10\x02" in frame[2:-2]:
            logging.error(f"DLE STX in frame: {frame}")
            serialHandler.reset()
            return
        if b"\x10\x03" in frame[2:-2]:
            logging.error(f"DLE ETX in frame: {frame}")
            serialHandler.reset()
            return

        # Compare calculated checksum to frame checksum
        if confirmChecksum(frame) == False:
            # If checksum doesn't match, message is invalid.
            # Clear buffer and don't attempt parsing.
            serialHandler.reset()
            return

        # Extract type and data from frame
        frameType = frame[2:4]
        data = frame[4:-4]

        # Use frame type to determine parsing function
        if frameType == FRAME_TYPE_KEEPALIVE:
            # Check to see if we have a command to send
            if serialHandler.ready_to_send == True:
                if commandHandler.keep_alive_count == 1:
                    # If this is the second sequential keep alive frame, send command
                    serialHandler.send(commandHandler.full_command)
                    logging.info(
                        f"Sent: {commandHandler.parameter}, {commandHandler.full_command}"
                    )
                    if commandHandler.confirm == False:
                        commandHandler.sending_message = False
                    serialHandler.ready_to_send = False
                else:
                    commandHandler.keep_alive_count = 1
            else:
                commandHandler.keep_alive_count = 0
        else:
            # Message is not keep alive
            commandHandler.keep_alive_count = 0
            if frameType == FRAME_TYPE_DISPLAY:
                parseDisplay(data, poolModel)
            elif frameType == FRAME_TYPE_LEDS:
                parseLEDs(data, poolModel)
            elif frameType == FRAME_TYPE_DISPLAY_SERVICE:
                parseDisplay(data, poolModel)
            elif frameType == FRAME_TYPE_SERVICE_MODE:
                logging.info(f"Service Mode update: {frameType}, {data}")
            # TODO add parsing and logging for local display commands
            # not sent by Pool-Pi (\x00\x02)
            else:
                logging.info(f"Unkown update: {frameType}, {data}")
        # Clear buffer and reset flags
        serialHandler.reset()


def checkCommand(poolModel, serialHandler, commandHandler):
    """
    If we are trying to send a message, wait for a new pool model to get pool states
    If necessary, queue message to be sent after second keep alive
    """
    if commandHandler.sending_message == False:
        # We aren't trying to send a command, nothing to do
        return

    if serialHandler.ready_to_send == True:
        # We are already ready to send, awaiting keep alive
        return

    if poolModel.timestamp >= commandHandler.last_model_timestamp_seen:
        # We have a new poolModel
        if (
            poolModel.getParameterState(commandHandler.parameter)
            == commandHandler.target_state
        ):
            # Model matches, command was successful.
            # Reset sending state.
            logging.info(f"Command success.")
            commandHandler.sending_message = False
            poolModel.sending_message = False
            poolModel.flag_data_changed = True
        else:
            # New poolModel doesn't match, command not successful.
            if commandHandler.sendAttemptsRemain() == True:
                commandHandler.last_model_timestamp_seen = time.time()
                serialHandler.ready_to_send = True


def getCommand(poolModel, serialHandler, commandHandler):
    """
    If we're not currently sending a command, check if there are new commands.
    Get new command from command_queue, validate, and initiate send with commandHandler.
    """
    if commandHandler.sending_message == True:
        # We are currently trying to send a command, don't check for others.
        return
    message = pubsub.get_message()
    if message and (message["type"] == "message"):
        messageData = json.loads(message["data"])
        # Extract command info
        commandID = messageData["id"]
        frontEndVersion = messageData["modelVersion"]

        if frontEndVersion != poolModel.version:
            logging.error(
                f"Invalid command: Back end version is {poolModel.version} but front end version is {frontEndVersion}."
            )

        # Determine if command requires confirmation
        if (commandID in button_toggle) or (commandID == "pool-spa-spillover"):
            commandConfirm = True
        elif commandID in buttons_menu:
            commandConfirm = False
        else:
            # commandID has no match in commands.py
            logging.error(f"Invalid command: Error parsing command: {commandID}")
            return

        if commandConfirm == True:
            # Command is not a menu button.
            # Confirmation if command was successful is needed

            # Pool spa spillover is single button- need to get individual commandID
            if commandID == "pool-spa-spillover":
                if poolModel.getParameterState("pool") == "ON":
                    commandID = "pool"
                elif poolModel.getParameterState("spa") == "ON":
                    commandID = "spa"
                else:
                    commandID = "spillover"

            # Check we aren't in INIT state
            if poolModel.getParameterState(commandID) == "INIT":
                logging.error(
                    f"Invalid command: Target parameter {commandID} is in INIT state."
                )
            # Determine next desired state
            currentState = poolModel.getParameterState(commandID)
            # Service tristate ON->BLINK->OFF
            if commandID == "service":
                if currentState == "ON":
                    desiredState = "BLINK"
                elif currentState == "BLINK":
                    desiredState = "OFF"
                else:
                    desiredState = "ON"
            # All other buttons
            else:
                if currentState == "ON":
                    desiredState = "OFF"
                else:
                    desiredState = "ON"

            logging.info(
                f"Valid command: {commandID} {desiredState}, version {frontEndVersion}"
            )
            # Push to command handler
            commandHandler.initiateSend(commandID, desiredState, commandConfirm)
            poolModel.sending_message = True

        else:
            # Command is a menu button
            # No confirmation needed. Only send once.
            # Immediately load for sending.
            commandHandler.initiateSend(commandID, "NA", commandConfirm)
            serialHandler.ready_to_send = True
    return


def sendModel(poolModel):
    """
    Check if we have new model for the front end. If so, send JSON data to redis.
    """
    if poolModel.flag_data_changed == True:
        r.publish("outbox", poolModel.toJSON())
        # socketio.emit("model", poolModel.toJSON())
        logging.debug("Published model to outbox.")
        poolModel.flag_data_changed = False
    return


def serialBackendMain():
    poolModel = PoolModel()
    serialHandler = SerialHandler()
    commandHandler = CommandHandler()
    while True:
        # Read Serial Bus
        # If new serial data is available, read from the buffer
        readSerialBus(serialHandler)

        # Parse Buffer
        # If a full serial frame has been found, decode it and update model.
        # If we have a command ready to be sent, send.
        parseBuffer(poolModel, serialHandler, commandHandler)

        # If we are sending a command, check if command needs to be sent.
        # Check model for updates to see if command was accepted.
        checkCommand(poolModel, serialHandler, commandHandler)

        # Send updates to front end.
        sendModel(poolModel)

        # If we're not sending, check for new commands from front end.
        getCommand(poolModel, serialHandler, commandHandler)


if __name__ == "__main__":
    # Create log file directory if not already existing
    if not exists("logs"):
        makedirs("logs")
    formatter = logging.Formatter(
        "%(asctime)s %(levelname)-8s %(message)s", datefmt="%Y-%m-%d %H:%M:%S"
    )
    handler = TimedRotatingFileHandler(
        "logs/pool-pi.log", when="midnight", backupCount=60
    )
    handler.suffix = "%Y-%m-%d_%H-%M-%S"
    handler.setFormatter(formatter)
    logging.getLogger().handlers.clear()
    logging.getLogger().addHandler(handler)
    logging.getLogger().setLevel(logging.INFO)
    logging.info("Started pool-pi.py")

    thread_web = Thread(target=webBackendMain, daemon=True)
    thread_web.start()
    serialBackendMain()

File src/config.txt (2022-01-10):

This file customizes the front end to match individual system setups.

Display names can be customized to match labels on physical units.
Unused controls can be hidden from front end.

Schema: PARAMETER = [DISPLAY_NAME, SHOW/HIDE]

FILTER = ["FILTER PUMP", SHOW]
LIGHTS = ["POOL LIGHT", SHOW]
HEATER1 = ["HEATER 1", SHOW]
VALVE3 = ["VALVE3", SHOW]
VALVE4 = ["VALVE4", SHOW]
AUX1 = ["SPA LIGHT", SHOW]
AUX2 = ["BLOWER", SHOW]
AUX3 = ["CLEANER", SHOW]
AUX4 = ["WATERFALL", SHOW]
AUX5 = ["AUX5", HIDE]
AUX6 = ["AUX6", HIDE]
AUX7 = ["AUX7", HIDE]
AUX8 = ["AUX8", HIDE]
AUX9 = ["AUX9", HIDE]
AUX10 = ["AUX10", HIDE]
AUX11 = ["AUX11", HIDE]
AUX12 = ["AUX12", HIDE
AUX13 = ["AUX13", HIDE]
AUX14 = ["AUX14", HIDE]

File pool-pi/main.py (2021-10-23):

import serial
from gpiozero import LED
from commands import *

buffer = bytearray()
buffer_full = False
command_queue = []
ready_to_send = False
send_enable = LED(2)
send_enable.off()
sending_attempts = 0
confirm_attempts = 0
looking_for_start = True
MAX_SEND_ATTEMPTS = 5  # Max number of times command will be sent if not confirmed
MAX_CONFIRM_ATTEMPTS = 20  # Max number of inbound message parsed to look for confirmation before resending command
previous_message = NON_KEEP_ALIVE

ser = serial.Serial(port='/dev/ttyAMA0',
                    baudrate=19200,
                    parity=serial.PARITY_NONE,
                    stopbits=serial.STOPBITS_TWO)


def readSerialBus():
    global looking_for_start
    global buffer
    global buffer_full
    if (ser.in_waiting != 0):
        if (looking_for_start == False):
            return
        if (buffer_full == True):
            return
        serChar = ser.read()
        while (serChar != STX):
            serChar = ser.read()
            #add timeout condition
        #we have STX
        buffer += DLE
        buffer += STX
        while (True):
            buffer += ser.read_until(DLE, 80)
            serChar = ser.read(
            )  #TODO Some conversion is taking place when storing to buffer and it affects comparison, need to investigate
            buffer += serChar
            if (serChar == ETX):
                break

        #add check for timeout
        looking_for_start = False
        buffer_full = True


def parseBuffer():
    global buffer_full
    global looking_for_start
    global ready_to_send
    global buffer
    global previous_message
    if (buffer_full):
        # Confirm checksum
        if (confirmChecksum(buffer) == False):
            print("Checksum mismatch! ", buffer)
        # Get message
        if (buffer == KEEP_ALIVE[0]):
            if previous_message != KEEP_ALIVE:
                print(KEEP_ALIVE[1])
                previous_message = KEEP_ALIVE
        else:
            previous_message = NON_KEEP_ALIVE
            print(buffer)
        buffer.clear()
        looking_for_start = True
        buffer_full = False
        ready_to_send = True


def confirmChecksum(message):
    target_checksum = buffer[-4] * (16**2) + buffer[
        -3]  # Convert two byte checksum to single value
    checksum = 0
    for i in message[:-4]:
        checksum += i
    if checksum == target_checksum:
        return True
    else:
        return False


def sendCommand():
    global command_queue
    global ready_to_send
    if (len(command_queue) != 0 and ready_to_send == True):
        # get command from queue and send
        # need flag for indicating command needs to be confirmed
        # need to initialize counters for command confirmation
        send_enable.on()
        ser.write()
        ser.flush()
        send_enable.off()
        ready_to_send = False


def getCommand():
    #TODO
    return


def updateModel():
    #TODO
    return


while (True):
    # Read Serial Bus
    readSerialBus()

    # Parse Buffer
    parseBuffer()

    # Update pool model
    updateModel()

    # Check for new commands
    getCommand()

    # Send to Serial Bus
    sendCommand()

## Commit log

2021-10-21 Loop for reading and printing commands.
2021-10-22 Bug fixes for appending to buffer and missing global references in functions.
    [main.py]
2021-10-23 Fixed == bug in parseBuffer and True/False bug in readSerialBus.
    [main.py]
2021-10-23 Fixed checksum math for single byte checksums.
    [main.py]
2021-10-23 Fixed end of message comparison check
    [main.py]
2021-10-23 Added check to prevent printing sequential keep alive messages.
    [commands.py, main.py]
2021-10-23 Fixed empty tuple syntax error
    [main.py]
2021-10-23 Fixed power operator syntax for checksum check (^ to **).
    [main.py]
2021-10-24 Fixed comparison bug checking for DLE
    [pool-pi.py]
2021-10-24 Fixed display flag comparison error.
    [commands.py, pool-pi.py]
2021-10-24 Swapped buffer for data in print statement while parsing.
    [pool-pi.py]
2021-11-09 Changed serial enable pin from GPIO2 to GPIO17 to work around default pin states from pi power up. GPIO17 defaults low on pi startup.
2021-11-16 Added error handling for utf-8 decoding
    [pool-pi.py]
2021-11-16 Added fix for : decode
    [pool-pi.py]
2021-11-17 Added degree symbol replacement.
    [pool-pi.py]
2021-11-17 Fixed degree utf-8 error
    [pool-pi.py]
2021-11-17 Fixed additional degree utf-8 bug
    [pool-pi.py]
2021-11-17 Fixed sep/end mistake in check system update print output.
    [pool-pi.py]
2021-11-27 Began implementing LED update detection
2021-11-27 Added parsing for LED byte 1.
2021-11-27 Fixed missing ) in LED_1
    [commands.py]
2021-11-27 Expanded parsing to all LEDs
2021-11-28 Switched flask start from flask run to app.run()
2021-11-28 Testing threading
2021-11-28 Fixed salt level decoding bug.
    [pool-pi.py]
2021-11-28 Fixed additional salt level bug.
    [pool-pi.py]
2021-11-30 Added socketio with no functionality
2021-11-30 Updated socket.io.js
2021-11-30 Moved jquery and socket js scripts offline
2021-11-30 Moved salinity update to dedicated socket event
2021-11-30 Fixed to only send model on updates
    [pool-pi.py]
2021-11-30 Fixed poolModel/model name issue
    [pool-pi.py]
2021-11-30 Fixed = == bug
    [pool-pi.py]
2021-12-09 Fixed air temp to include value+units
    [pool-pi.py]
2021-12-09 Fixing air temp parse
    [pool-pi.py]
2021-12-09 Super professional print debugging
2021-12-09 Air temp fix cont.
    [pool-pi.py]
2021-12-09 Fixed : decoding in parseDateTime
    [pool-pi.py]
2021-12-09 Fixed salinity parsing for very low salt case
    [pool-pi.py]
2021-12-09 Working on adding switches
2021-12-10 Fixed waterfall led logic
    [pool-pi.py]
2021-12-10 Troubleshooting led messages
2021-12-11 Updated model on command send to prevent model from overwriting new command
    [pool-pi.py]
2021-12-13 Refactoring. Updated PoolModel. Created SerialHandler class. Updated LED structure. Added attribute states.
2021-12-14 Renamed LED bitmask to prevent name collision
    [commands.py, pool-pi.py]
2021-12-14 Fixed LED bug and added blink detection
    [pool-pi.py]
2021-12-14 Fixed aux9 LED naming issue
    [commands.py]
2021-12-14 Filtered out flag_data_changed in front end JSON parser
2021-12-15 Working on adding in switches
2021-12-15 Testing multiple switches
2021-12-15 Fixed output for switches
2021-12-15 Cleaned up switch outputs. Added emit to backend on switch change.
2021-12-16 Switched checksystem to LED instead of switch/versioned control. Added switches to all parameters. Added switch state from front end.
2021-12-16 Re-added versioning for switches. Added command validation via versioning.
2021-12-16 Updated threading
2021-12-16 Trying file write for thread workaround
    [pool-pi.py, web.py]
2021-12-16 Fixed file write args.
    [web.py]
2021-12-16 Reverted thread starts. Expanded getCommand.
    [pool-pi.py]
2021-12-16 Fixed command string creation
    [web.py]
2021-12-16 Debugging version key error
    [web.py]
2021-12-27 Added error handling for parseAirTemp
    [parsing.py]
2021-12-27 Added buffer clear if checksum doesn't match instead of attempting to parse message.
    [pool-pi.py]
2021-12-27 Fix bool to str in command
    [web.py]
2021-12-27 Fixed readlines missing ()
    [pool-pi.py]
2021-12-27 Fixed command version check (str vs int)
    [pool-pi.py]
2021-12-27 Added switch from true/on and false/off
2021-12-28 Fixed send/write name issue
    [pool-pi.py]
2022-01-01 Added timestamps for LED/model messages and logic for ensuring a new model update has been seen before retrying a command. Adjusted send time delay.
2022-01-02 Added in aux 7-14 (need to filter on LED parse)
2022-01-03 Updated switch colors to match physical interface.
2022-01-03 Fixed css and valve names.
2022-01-03 Fixed sizing bug for last row of switches
2022-01-03 Added hover effect for switches
2022-01-04 Updated license to explicitly call out jquery and socket.io licenses.
2022-01-04 Fixed typo and added additional check for checkCommand.
    [pool-pi.py]
2022-01-05 Fixed class/object name issue
    [pool-pi.py]
2022-01-05 Fixed aux3 command (swapped with service)
    [model.py]
2022-01-07 Added test button
2022-01-07 Added second button and css
2022-01-07 Fixed button bug
2022-01-07 Added additional buttons
2022-01-09 Fixed json bug from missing copy()
    [model.py]
2022-01-09 Updated frame forming to add x00 after x10
2022-01-10 Added config.txt
    [config.txt]
2022-01-10 Added menu-type button functionality.
2022-01-10 Updated display parsing to update changed flag even if error occurs
    [parsing.py]
2022-01-11 Added input flush when checksum error occurs.
    [model.py, pool-pi.py]
2022-01-11 Added checksum error printing
    [parsing.py]
2022-01-12 Added overlay on switch toggle
2022-01-12 Added basic button effect, broke panel css
2022-01-13 Fixed mask logic bug
    [parsing.py]
2022-01-14 Overhauled front end. Swapped toggles to buttons. Added blinking leds. Added check system LED.
    [model.py]
2022-01-14 Reset LEDs to off. Adjusted overlay.
2022-01-14 Fixed other button state check
2022-01-14 Added immediate overlay on button push
2022-01-15 Updated updateParameter to fix checkSystem LED
    [model.py]
2022-01-15 Updated led mask names
2022-01-16 Moved superchlorinate and systemoff from buttons to states.
2022-01-17 Added raspberry pi setup tutorial link
2022-01-17 Updated logging and fixed bug in parseLED logging
    [parsing.py, web.py]
2022-01-17 Cleaned up comments and printing
2022-02-13 Updated wire details in parts list
2022-05-13 Updated wiring_2 diagram. Added Fritzing file.
    [pool-pi_v2.fzz]
2022-05-23 Corrected selection and add event listener loop for menu buttons. Removed unused on connect function.
2022-06-20 Added cursor change to pointer when mouse hovers over buttons.
2023-01-06 Added 1k pull down to DE to prevent DE from being pulled to 5V during pi startup. Updated parts list, setup, and wiring image.
    [pool-pi_v2.fzz]
2023-01-26 Added pcb files and updated documentation.
    [pool_pi_v1.1.kicad_pcb, pool_pi_v1.1.kicad_sch]
2023-02-04 Corrected parsing of front end command.
    [web.py]
2023-02-04 Fixed int to str error.
    [web.py]
2023-02-04 Fixed pool/spa/spillover next state logic.
    [pool-pi.py]
2023-02-04 Fixed pool-spa-spillover from falsely throwing error
    [pool-pi.py]
2023-02-04 Corrected menu button front end to back end message format.
2023-11-19 Using socketio from cdn instead of offline.
2023-11-19 Fixed web function name
    [web.py]
2023-11-24 Removed print statement for debugging.
2023-11-24 Switched socket.io to v4.6.0
2023-11-24 Updated docs to enable UART.
2024-12-28 Corrected setup script. Added allow_unsafe_werkzeug.
    [web.py]
